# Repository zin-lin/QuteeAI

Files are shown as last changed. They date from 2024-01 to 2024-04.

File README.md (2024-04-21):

# Qutee_v2
Repository for the base code and design of the Qutee V2 robot

# Environment Setup
Setup your Linux environment and Docker.

## Linux
For Linux, you can choose WSL **OR** a VM

### Window Subsystem for Linux ```(WSL)```
Allows a linux distro to run directly on a Windows machine. The default distro will be ```Ubuntu```

- Step 1 - WSL install command
  - Open powershell or windows cmd in administrator mode
  - Enter the command, then restart your machine 

  ```powershell
    wsl --install
  ``` 
*For more info: https://learn.microsoft.com/en-us/windows/wsl/install*
### Virtual Machine ``(VM)``
TBC

## Docker
- Step 1 - Install Docker Desktop
  - Download docker desktop on Windows (https://www.docker.com/products/docker-desktop/)

### ``WSL ONLY``
- Step 2 - Modify Docker Settings
  - Ensure "Use the WSL 2 based engine" is checked.
  - Go to **Settings > Resources > WSL > Enable Integration**

*For more info: https://learn.microsoft.com/en-us/windows/wsl/tutorials/wsl-containers*

---

# Installing `ROS2`

- Step 1 - Set Locale
    ```shell
    locale  # check for UTF-8

    sudo apt update && sudo apt install locales
    sudo locale-gen en_US en_US.UTF-8
    sudo update-locale LC_ALL=en_US.UTF-8 LANG=en_US.UTF-8
    export LANG=en_US.UTF-8

    locale  # verify settings
    ```
- Step 2 - Enable required respositories

    - Enable Ubuntu Universe repository
    ```shell
    sudo apt install software-properties-common
    sudo add-apt-repository universe
    ```

    - Add the ROS 2 GPG key with apt
    ```shell
    sudo apt update && sudo apt install curl -y
    sudo curl -sSL https://raw.githubusercontent.com/ros/rosdistro/master/ros.key -o /usr/share/keyrings/ros-archive-keyring.gpg
    ```

    - Add the repository to your sources list
    ```shell
    echo "deb [arch=$(dpkg --print-architecture) signed-by=/usr/share/keyrings/ros-archive-keyring.gpg] http://packages.ros.org/ros2/ubuntu $(. /etc/os-release && echo $UBUNTU_CODENAME) main" | sudo tee /etc/apt/sources.list.d/ros2.list > /dev/null
    ```

- Step 3 - Install ROS2

    - Update your apt repository caches after setting up the repositories.
    ```shell
    sudo apt update
    ```
    - Make sure system is up to date
    ```shell
    sudo apt upgrade
    ```
    - Install ROS2
    ```shell
    sudo apt install ros-humble-desktop
    ```

- Step 4 - Setup Environment
    ```shell
    source /opt/ros/humble/setup.bash
    ```

- Step 5 - Test
    ```shell
    ros2 wtf
    ```
  -  Should say "All 5 Checks Passed"

*For more info: https://docs.ros.org/en/iron/Installation/Ubuntu-Install-Debians.html*
## Getting Access to Repository on `Linux`
- Step 1
  - In your Linux/Ubuntu VM/Ubuntu App/WSL Powershell, generate SSH key, please keep it out of the repo dir
  ```shell
  ssh-keygen
  ```

- Step 2
  - name the generated key anything you want and skip the `re-paraphrasing` bit
  - this will generate the `$name.pub` file and the `$name`, where the later is the private and the former the public key.
- Step 3
  - Request `zin-lin` on Discord and send your `$name.pub` file's content.
- Step 4
  - activating your key on Local Linux on your system.
  - ```shell
    eval "$(ssh-agent -s)"
    ssh-add path/to/your/private/file/$name
    ```
- Step 5
  - See if your key connection works
  - ```shell
    ssh git@githum.com
    ```
  - The following will be printed if it does
  - ```shell
    PTY allocation request failed on channel 0
    Hi zin-lin/QuteeAI! You've successfully authenticated, but GitHub does not provide shell access.
    Connection to github.com closed.
    ```
- Step 6 
  - Allocate where you want the project and pull
  - ```shell
    mkdir qtai
    cd qtai
    git init
    git remote add origin git@github.com:zin-lin/QuteeAI.git
    git pull origin master
    ```

# Software Compilation and Process
The Software for the Qutee Robot will mainly depend on what hardware component is used during the assembly process.
Use the `Adaptive` folder if you are following what `adaptive-intelligent-robotics` are doing. 
Otherwise, for simple operations and starting with Robotics you may use any other folder inside `software` folder.
The following are components are for all solutions. 

## Electronics Hardware Components

- `12x` XL330 m288t or XL330 m077 Motors [Dynamixel.](https://robotis.co.uk/robotis-dynamixel-xl330-m288-t.html)
- `1x`  Adafruit ESP32s3 Reverse Feather TFT [Adafruit.](https://learn.adafruit.com/esp32-s3-reverse-tft-feather/overview)
  - Do Not buy the [ESP32s3 TFT](https://learn.adafruit.com/adafruit-esp32-s3-tft-feather/overview) because we are not sure if that solution will work or not as the `Dynamixel2Arduino` Library is not transmitting `TX channel` on said board.
- `1x` Dynamixel Shield [Dynamixel.](https://learn.adafruit.com/adafruit-esp32-s3-tft-feather/overview)
- `1x` Dynamixel U2D2 PHB [Dynamixel.](https://emanual.robotis.com/docs/en/parts/interface/u2d2_power_hub/)
- `1x` Dynamixel U2D2 Device [Dynamixel.](https://emanual.robotis.com/docs/en/parts/interface/u2d2/)
- `1x` Arduino Uno Rev 3 Board [Arduino.](https://docs.arduino.cc/hardware/uno-rev3/)
- `1x` Arduino ESP32 Nano [Arduino.](https://docs.arduino.cc/hardware/nano-esp32/)

### Please follow the commands under the software folder to deal with Firmware build and flash.

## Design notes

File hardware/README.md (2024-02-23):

## CAD Design ##
The design of the robot can be found [online with Fusion 360](https://a360.co/49cv0nH).

[Also Here](https://myhub.autodesk360.com/ue2c9bb1e/g/shares/SH512d4QTec90decfa6e1e6c72c091da29c5).

## Print List ##
The STLs of the different elements are available in the STL folder. Here is the print list:
|  Qty | Name of the file  | 
|---|---|
| 1x |body_base|
| 1x |body_bottom|
| 1x |case|
| 1x |case_botom|
| 4x |doubleU|
| 4x |foot|
| 12x |horn|
| 12x |horn_spacer|
| 8x |side|
| 1x |spacer|
| 4x |tibia|

## Bill of Material ##
|  Min. Qty. | Reference  | Example of provider | 
|---|---|---|
|12x| Motor: Robotis - Dynamixel XL330-M288-T| https://robosavvy.co.uk/robotis-dynamixel-xl330-m288-t.html|
|1x| Micro-controller: Adafruit ESP32-S3 Reverse TFT Feather - 4MB Flash, 2MB PSRAM, STEMMA QT (for non-TFT: Adafruit ESP32-S3 Feather with 4MB Flash 2MB PSRAM - STEMMA QT / Qwiic| [https://shop.pimoroni.com/products/adafruit-esp32-s3-feather-with-4mb-flash-2mb-psram-stemma-qt-qwiic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](https://thepihut.com/products/adafruit-esp32-s3-reverse-tft-feather-4mb-flash-2mb-psram-stemma-qt)|
|1x| IMU: Adafruit 9-DOF Absolute Orientation IMU Fusion Breakout - BNO055 (STEMMA QT / Qwiic)| [https://robosavvy.co.uk/sparkfun-9dof-imu-breakout-ism330dhcx-mmc5983ma-qwiic.html](https://thepihut.com/products/adafruit-9-dof-absolute-orientation-imu-fusion-breakout-bno055-stemma-qt-qwiic)|
|1x| IMU cable: Flexible Qwiic Cable - 100mm| https://robosavvy.co.uk/flexible-qwiic-cable-100mm.html|
|1x| Battery: 2/3 AF 1600mAh 4.8V Square Premium Sport NiMH Battery| https://www.overlander.co.uk/nimh-batteries/4-8v-4s/2-3-af-1600mah-4-8v-square-premium-sport-nimh-battery.html (You will need a charger for this too). |
|1x| Power Board: ROBOTIS - U2D2 PHB SET| https://robosavvy.co.uk/robotis-u2d2-phb-set.html|
|1x| Battery connector: Molex, Mini-Fit Jr Receptacle Connector Housing, 4.2mm Pitch, 2 Way, 2 Row| https://uk.rs-online.com/web/p/wire-housings-plugs/4841748|
|2x| Battery connector contacts: Molex MINI-FIT Series, 5556 Series Number, Crimp Contact, Female, 24AWG to 18AWG, Tin Plating| https://uk.rs-online.com/web/p/crimp-contacts/1729134|
|100x| screw: Pozidriv Countersunk M2x10mm|https://uk.rs-online.com/web/p/machine-screws/1795670 |
|100x| screw: Pozidriv Pan M2x5mm|https://uk.rs-online.com/web/p/machine-screws/9141466| 

# for custom cables: #
The cables are made in-house at custom length. This is not mandatory, it just allows better cable management. Otherwise, the cables that come with the motors should be enough to build the robot (not tested). To make custom cables, you will need: 
|  Min. Qty. | Reference  | Example of provider | 
|---|---|---|
|1x| |https://uk.rs-online.com/web/p/hook-up-wire/8417263|
|1x| |https://uk.rs-online.com/web/p/insertion-extraction-tools/3253500|
|1x| |https://uk.rs-online.com/web/p/crimp-tools/4482355|
|75x| |https://uk.rs-online.com/web/p/crimp-contacts/3116439|
|24x| |https://uk.rs-online.com/web/p/wire-housings-plugs/1724910|

# optional #
If you don't want to print the horns and horn_spacers, you can buy the following which provides 4 pairs along with the frame that is not used. 
|  Qty | Name  | Example of provider | 
|3x| spacers and horns: FPX330-H101 4PCS SET| https://robosavvy.co.uk/fpx330-h101-4pcs-set.html (I used the spacers from this kit, but I will check in the near future if that can be 3d printed)|

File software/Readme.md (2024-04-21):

# Firmware
Please read the main Readme before reading this. 
There solutions are provided 
1) Using `esp32s3` (8MB for RAM) - Developed by [adaptive-intelligent-robotics](https://github.com/adaptive-intelligent-robotics/Qutee_v2)
   - wifi ✅, self-processing ✅, usb-debugging ❌
2) Using `Arduino Uno` and potentially wifi `Nano-esp32` (very powerful at 16MB of RAM for a microcontroller). Self-development
   - wifi ✅, self-processing ✅, usb-debugging -`testing`
3) Using `U2D2 device` (No RAM). Self-development
   - wifi ❌, self-processing ❌, usb-debugging ✅
###
- #### For the first solution please visit the repository made by the original developers.

### Hardware preparation 

- Before we do anything with the code the Dynamixel motors are needed to be set up so that all three solutions are usable.
- The servos when they come in, all have the `ID = 1`, which needed to be changed to `11`, `12`, `13`, `21`, `22`, `23`, `31`, `32`, `33`, `41`, `42`, `43`
- This can be done using the `U2S2` device and `Dynamixel Wizard` Application [Dynamixel](https://emanual.robotis.com/docs/en/software/dynamixel/dynamixel_wizard2/)
  - Please download this application on your PC.
  - Then connect the U2D2 device with the PC using USB-A and start the `Dynamixel Wizard`.
  - Just to be sure you must select to update the firmware on the servo
    - Select the right model and upload firmware
    - Then hit scan 
    - and now you will see your servo
    - set the ID to the ones given above
    - Note: do this one by one: do not daisy-chain them 
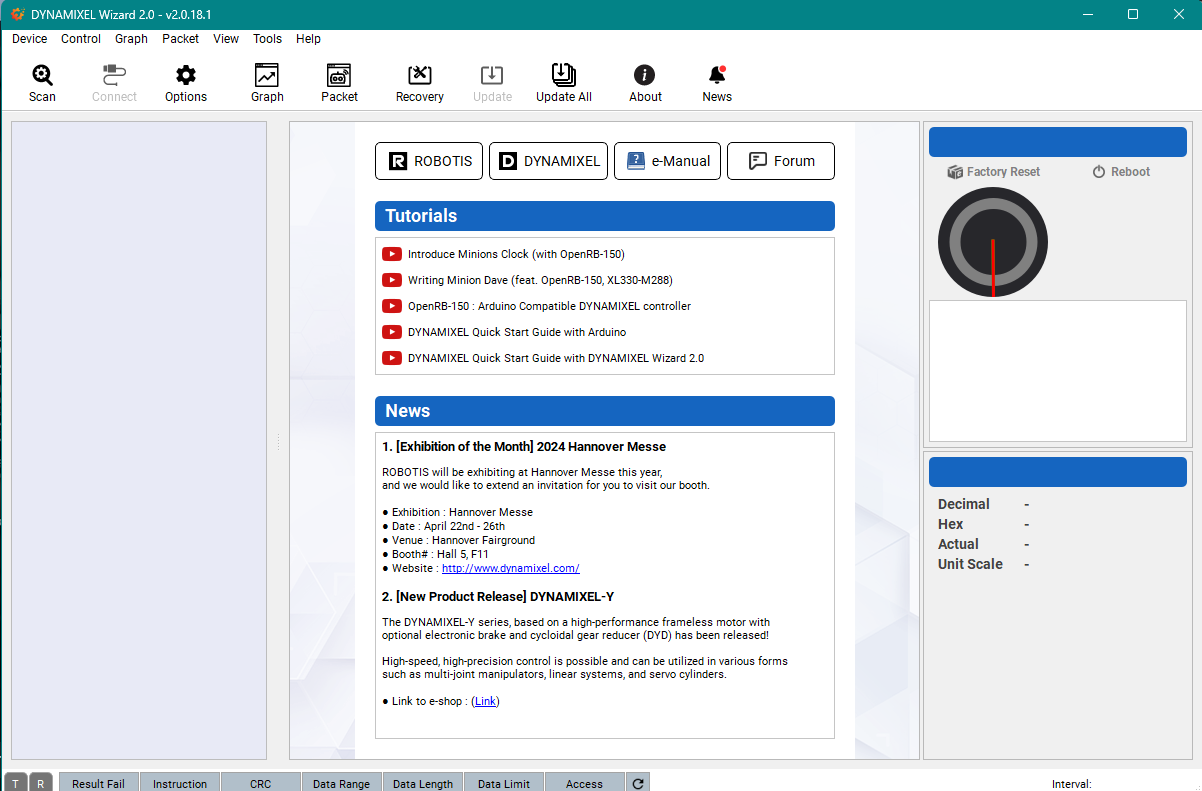
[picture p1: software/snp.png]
Wizard
    - 
- We must now continue to create Y cables out of the two given 3 pins wires (`GND`, `VAT`, `DATA`). 
This is because either if we use U2D2 PHB, or the Dynamixel shield solutions or the U2D2 solution, we still will have only two available 3pin Dynamixel slots. We need four legs.
- Thus 2, 3pin wires must be crimped. 

### Solution 1
- For the first solution, one must connect the GND pin on the ESP32s3 to the GND pin on one of the sockets of the 3 pin ports on the PHB.
Then the VBat to the VAT line and use crimps to connect two wires which are soldered to A0 and A1, which then connects to the data line on the PHB.
    - ESPCon
- Then use the remaining two ports to connect to the Y cables created earlier for four legs. Each port will control two legs
- Now we can daisy-chain the legs.
- Remember to keep the order on 
  - `leg 1` - `11` , `12`, `13`
  - `leg 2` - `21` , `22`, `23`
  - `leg 3` - `31` , `32`, `33`
  - `leg 4` - `41` , `42`, `43`
 - Software solution for this should be followed as instructed by the Original Developers on the given url.

### Solution 2
- For the second solution, using the Arduino boards one must download the Arduino IDE
- then through package manager, one must download the Arduino Uno Support Libraries
- Still in testing later use for processing and cloud connection download `Nano ESP32 Arduino` library as well.
- The next thing that one needs are the `DynamixelSheild` and `Adafruit_BNO055` library. This has to be downloaded via Library Manager as well.
- The current status of this solution is that it can walk, WiFi and imu will be added later using the `Nano ESP32 Arduino`
- Here the hardware components are easier to manage. 
  - Connect the Arduino Board and the Sheild by stacking them, they should fit perfectly.
  - Connect the four terminal servos as solution 1 to the shield just like to the PHB. 
  - Move the shield switch to UART and upload the `solution_flash.ino` file onto the board.
  - Hit RsT button 
  - The robot should start moving
  - disconnect batteries to stop.
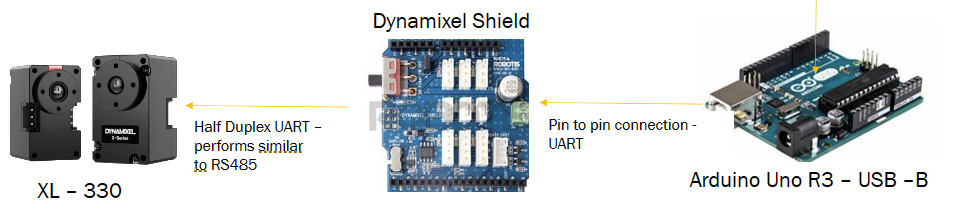
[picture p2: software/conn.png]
Connection
  - 

### Solution 3
- This is using the U2D2 and the PHB set for it 
- For this you would need to set up the `USB - A` Connection between the PC and the U2D2 device.
- This device can be mounted on top of the PHB board and connect to the pin board using Dynamixel 3 pin cables.
- Now the set up of the motors should be the same as Solution 1, where the remaining 3 pin sockets should be connected to the Y cable, each managing two legs worth of servos.
- Before running the code run
  - ```shell
    pip3 install dynamixel_sdk
    ```
- Run the code, remember to replace the `Dev/ttyACM0` with your correct port.
- If running on WSL make sure to download `USBIPD-WIN` and use binding to use port.
  - ```shell
    usbipd list
    usbipd bind  --busid <your-bus-id>
    usbipd attach --wsl --busid <your-bus-id>
    ```
- You can use docker to build this solution by using the Dockerfile as well. But remember to allow Docker to share port as well.

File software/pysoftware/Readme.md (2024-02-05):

# Damian's way for deploying https and http -VM name/VM IP with Caddy and Flask/wsgi-waitress

- Step 0: make sure `your_repo` in `gen-waitress.sh` is `your repo address/folder` and `Description=Your App Name` is actually `Description= whatever_you_want_to_name_it` and also in your Caddyfile change `xx` to `your napier machine no. example 23`
- Step 1: run 
```powershell
chmod +x run.sh
```
- Step 2: run the file
if installation needed/ run for the first time
```powershell
./run.sh install
```
else run after changes
```
./run.sh
```

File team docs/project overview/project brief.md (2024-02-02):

## Build a quadruped robot for Artificial Intelligence research
Edinburgh Napier University
C++ , GIT , Linux , Machine learning , Microprocessors , Python , Raspberry Pi , Sensors

#### Overview
With the use of 3D printers and accessible hardware like micro computers and servo motors, we can build robots in-house that are ready to be used in academic research. In this project, the group will build and test a Qutee robot. The Qutee is an open-source quadruped robot. All the parts to build the robot are easily found on the market and 3D printed with the facilities at ENU.

The group will 3D print the legs and body of the robot, assemble them, including the motors, controller (CPU and motor hub) and battery. Then, the group will program the robot to tests its capacities. The second part of the project includes the use of artificial intelligence to make the robot autonomous. At this point, several techniques can be applied, like machine learning, evolutionary computation or intrinsic motivations.

An example of the robot used for research can be found here: https://arxiv.org/abs/2304.12080 https://www.youtube.com/watch?v=BgGNvIsRh7Q

#### Deliverables
The main deliverable is the robot itself. The robot will be 3D printed by the students using the printers and material provided by the university. The university will provide all the hardware also to fully assemble the robot: motors, controller, cabling, etc.

Other deliverable include the software to control the robot. This code can be stored in our git repository. This software should include the actions to send to the motors (joint angle position) and the reading of the sensors included in the robot (IMU, joint positions, etc). An interface to the most used robotic software like Python and ROS can be built for this project.

Last deliverable is the autonomous control of the robot using some of the AI techniques mentioned before.

A report with a list of improvements for future iterations of the robot.

#### Resources
All the hardware necessary to print the robot parts (3D printers, plastic material, etc).

The hardware to assembly the robot (motors, sensors, controller, cables, battery, charger, etc).

CAD description for the 3D printed parts.

Access to lab B62 to work on the robot and print the parts.

The software can be written in any language but Python or C++ are the most used for robotics.

Knowledge of ROS is a plus but not required. Knowledge of AI and machine learning is also a plus but is not required.

#### Contact details
The client will contact you after you form a team and register a bid for the project.

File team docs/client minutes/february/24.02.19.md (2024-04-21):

## Client Meeting Minutes  

Date:19/02/2024  
Location: B62

Client: Simón Smith, C82e
Sponsor: Alex Gkanatsios, B69b

Attendees:

|Name|Role|In Person|Online|
|:--|:--|:--:|:--:|
|Malcolm Byrnes| PM | [x] | [ ] |
|Guy Cameron | Test Lead | [x] | [ ] |
|Zin Htun | Software Lead | [ ] | [x] |
|Nicole Jordaan | Scrum Master | [ ] | [x] |
|Aman Mishra | Hardware Lead | [x] | [ ] |
|Andrew Taison | PO | [x] | [ ] |

---  

#### Progress:  
(Since last meeting)  

* Reply from github repo owners  
* 3d parts stl files have been modified  
* Purchased parts have been delivered (missing 7 motors as mentioned last week)  
* Can now visualise URDF files  

---  

#### Agenda:  
(What was discussed)  

* Reply recieved from github repo owners, they are flushing software to micro-controller, still communicating with them. Don't think ESP can handl ROS2, suspect one module is not compatible  
* STL of new version of leg (one part) has been completed, all printing is expected to be complete by late tomorrow
* Expecting to start looking at soldering boards and testing motors tomorrow  
* Documentation on dynamixel for voltages to send to motors and how to connect etc. **Important** to not damage motors as will not be able to get any more  
* Client appreciates documentation being created  
* Can visualise URDF, but struggling to intergrate STL or dae files as mesh to create URDF  

---  

#### Decisions:  
(Project decisions made)  

* Read (joint positions/IMU) along with ability to set joint positions is sufficient for project - worrying about communication via ROS etc can be a later issue    
* Need to use these motors - as only have 5, can only assemble what we have. Maybe assemble rest in a way that can be disassembled easily when other motors arrive. Should have ability to move a little, even crawling  
* Ok to create URDF file with basic shapes instead of using STL, this can maybe be added later to make it look better if can find a way to intergrate, but a lower priority. Can potentially get center of mass values for URDF from fusion (need to look into), however, will be ok to use center of part as center of mass, and set mass as 0.1kg or something (very light - NOT zero)  

---  

#### Action Items:  
(Items to be completed, reponsible person and completion date if applicable)  

* Send video to Simon if build robot and have it moving (even if just 1 leg) - **@everyone**  
* Start URDF creation for actual robot with basic shapes - **@Andy**  
* Look into obtaining part details (mass / center of mass / inertia details etc) from fusion 360 - **@Guy**  
* Look into if its possible to integrate STL files with URDF (or if theres a specific file type that URDF allows for mesh files) - **@Guy**  
* Test motors - **@Damian**  
* Start documentation - **@Nicole**  
* Start soldering IMU/ada/power board pins - **@Aman / @Andy**  
* Management duties, docs, collect parts - **@Malcolm**  

---  

#### Next Meeting:
(When and where)  

* Monday 26th February - B62 and online

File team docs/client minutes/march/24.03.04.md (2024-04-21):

## Client Meeting Minutes  

Date: 04/03/2024  
Location: B62

Client: Simón Smith, C82e
Sponsor: Alex Gkanatsios, B69b

Attendees:

|Name|Role| In Person | Online |
|:--|:--|:---:|:-----:|
|Malcolm Byrnes| PM | [x] |  [ ]  |
|Guy Cameron | Test Lead | [x] |  [ ]  |
|Zin Htun | Software Lead | [x] |  [ ]  |
|Nicole Jordaan | Scrum Master | [x] |  [ ]  |
|Aman Mishra | Hardware Lead | [ ] |  [x]  |
|Andrew Taison | PO | [x] |  [ ]  |

---  

#### Progress:  
(Since last meeting)  

* Most parts have been printed  
* Original code is compiling  
* Soldering the board has started

---  

#### Agenda:  
(What was discussed)  
* Discussed Reprinting of TFT spacer - Needs to be done ASAP and sent to Alex 
* Showed URDF file to client
* Discussed URDF file is able to be opened in Issac Gym but collisions haven't been setup
* Discussed minor changes to URDF file
* Discussed battery cable modification
* Discussed how motors are to be connected to microcontroller 
---  

#### Decisions:  
(Project decisions made)  

* Building the robot can be started

---  

#### Action Items:  
(Items to be completed, reponsible person and completion date if applicable)  

* Collisions  to be added to URDF file
* The battery cable will need to be modified to connect to power board
* Ask original developers how to connect the motors to  microcontroller 

---  

#### Next Meeting:
(When and where)  

* Monday 11th March - B62 and online

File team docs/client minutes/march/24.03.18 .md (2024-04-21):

## Client Meeting Minutes  

Date: 18/03/2024  
Location: B62

Client: Simón Smith, C82e
Sponsor: Alex Gkanatsios, B69b

Attendees:

|Name|Role| In Person | Online |
|:--|:--|:---:|:-----:|
|Malcolm Byrnes| PM | [x] |  [ ]  |
|Guy Cameron | Test Lead | [x] |  [ ]  |
|Zin Htun | Software Lead | [x] |  [ ]  |
|Nicole Jordaan | Scrum Master | [x] |  [ ]  |
|Aman Mishra | Hardware Lead | [x] |  [ ]  |
|Andrew Taison | PO | [x] |  [ ]  |

---  

#### Progress:  
(Since last meeting)  

* Motors are working and we have basic control
* Construction in progress
* All parts now printed
* Different battery being used as previous was incompatible
* Old battery not enough voltage, needs to be larger

---  

#### Agenda:  
(What was discussed)  
* Discussed problems with power from battery
* Discussed and solved clearance issues with double u and legs
---  

#### Decisions:  
(Project decisions made)  

* Continue building robot

---  

#### Action Items:  
(Items to be completed, reponsible person and completion date if applicable)  

* Forget battery and use wired power
* Continue working with u2d2
* Forget wifi
* Try to connect imu to read the state of the motors
* Use different screws for connecting double u and legs

---  

#### Next Meeting:
(When and where)  

* Unknown? Probably after Easter Break

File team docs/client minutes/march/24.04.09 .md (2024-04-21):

## Client Meeting Minutes  

Date: 09/04/2024  
Location: E13

Client: Simón Smith, C82e\
Sponsor: Imed Romdhani, C64

Attendees:

|Name|Role| In Person | Online |
|:--|:--|:---:|:-----:|
|Malcolm Byrnes| PM | [x] |  [ ]  |
|Guy Cameron | Test Lead | [ ] |  [ ]  |
|Zin Htun | Software Lead | [x] |  [ ]  |
|Nicole Jordaan | Scrum Master | [x] |  [ ]  |
|Aman Mishra | Hardware Lead | [x] |  [ ]  |
|Andrew Taison | PO | [x] |  [ ]  |

---  

#### Progress:  
(Since last meeting)  

* Robot mostly build
* New crimps and molex arrived
* Attempted implementation with wifi
* URDF updated

---  

#### Agenda:  
(What was discussed)  
* Discussed potential problem with either software or hardware
* Discussed connecting wires, crimps too small, y cable could be potential solution
* start of project closure
---  

#### Decisions:  
(Project decisions made)  

* Continue building robot
* Use arduino uno for demo, stick it on robot temporarily
* Write documentation on hardware and software
* work on solutions for cables
* scrapping esp idea

---  

#### Action Items:  
(Items to be completed, reponsible person and completion date if applicable)  

* mounting arduino uno onto robot
* sort cabling out

---  

#### Next Meeting:
(When and where)  

* 15/04/2024 B62

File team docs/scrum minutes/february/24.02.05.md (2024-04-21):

## Scrum Meeting Minutes  

Date: 05/02/2024 
Location: --

Client: Simón Smith, C82e
Sponsor: Alex Gkanatsios, B69b

Attendees:

|Name|Role|In Person|Online|
|:--|:--|:--:|:--:|
|Malcolm Byrnes| PM | [ x ] | [ ] |
|Guy Cameron | Test Lead | [ x ] | [ ] |
|Zin Htun | Software Lead | [ x ] | [ ] |
|Nicole Jordaan | Scrum Master | [ x ] | [ ] |
|Aman Mishra | Hardware Lead | [ x ] | [ ] |
|Andrew Taison | PO | [ x ] | [ ] |

---  

#### Blockers:  
(What cannot progress, why, any actions required to continue?)  

*  Still waiting for parts to print.
*  Still waiting for electronic components to arrive.
*  Software is confusing to read and cannot build it.

---  

#### Progress:  
(Since last meeting)  

*  Most sections of the IR report have been completed.
*  Most people (4/6) have Linux with Docker setup.

---  

#### Agenda:  
(What was discussed)

*  Who still needs to set up Linux and Docker.
*  What still needs to be done with the IR report.
*  How to modify the top case to accommodate the new design of the microcontroller.
*  What is URDF file and how to create one.

---  

#### Decisions:  
(Project decisions made)  

* Made the descion to try to use fusion 360 to modify the case

---  

#### Action Items:  
(Items to be completed, reponsible person and completion date if applicable)  

*  Complete Executive Summary Section of the IR report - assigned to Malcolm
*  Stakeholders Map needs to be added to IR Report - assigned to Aman
*  Expected Costs and Duration section needs to be reviewed - assigned to Nicole
*  Research URDF file - assigned to Andy
*  Research Fusion 360 - assigned to Guy
*  Research ROS2 - assigned to Zin 

---  

#### Next Meeting:
(When and where)  

*   12/02/2024 on Campus

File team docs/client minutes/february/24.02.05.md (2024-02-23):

## Client Meeting Minutes  

Date:05/02/2024  
Location: B62

Client: Simón Smith, C82e
Sponsor: Alex Gkanatsios, B69b

Attendees:

|Name|Role|In Person|Online|
|:--|:--|:--:|:--:|
|Malcolm Byrnes| PM | [x] | [ ] |
|Guy Cameron | Test Lead | [x] | [ ] |
|Zin Htun | Software Lead | [x] | [ ] |
|Nicole Jordaan | Scrum Master | [x] | [ ] |
|Aman Mishra | Hardware Lead | [x] | [ ] |
|Andrew Taison | PO | [x] | [ ] |

---  

#### Progress:  
(Since last meeting)  

* Continued initiation report  
* 

---  

#### Agenda:  
(What was discussed)  

* Parts still not here - follow up email has been sent (by Simon) **"Pending stock"**
* Discussed stakeholder map  
* Discussed Git Software for project - Libraries discontinued  

---  

#### Decisions:  
(Project decisions made)  

* Robot would not be expected to move in a perfect straight line  

---  

#### Action Items:  
(Items to be completed, reponsible person and completion date if applicable)  

* Simon to look into alternatives for motors if unable to obtain (do to stock issues) **@Simon**  
* Look into Fuision 360 for adjusting design for case to accomodate dev board  
* Research URDF files  

---  

#### Next Meeting:
(When and where)  

* Monday 12th February - B62 and online

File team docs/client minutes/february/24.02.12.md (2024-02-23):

## Client Meeting Minutes  

Date:12/02/2024  
Location: B62

Client: Simón Smith, C82e
Sponsor: Alex Gkanatsios, B69b

Attendees:

|Name|Role|In Person|Online|
|:--|:--|:--:|:--:|
|Malcolm Byrnes| PM | [x] | [ ] |
|Guy Cameron | Test Lead | [x] | [ ] |
|Zin Htun | Software Lead | [x] | [ ] |
|Nicole Jordaan | Scrum Master | [x] | [ ] |
|Aman Mishra | Hardware Lead | [x] | [ ] |
|Andrew Taison | PO | [x] | [ ] |

---  

#### Progress:  
(Since last meeting)  

* Finished and submitted PIR  
* Printing continues   
* Looked into fusion  
* Looked into URDF files  

---  

#### Agenda:  
(What was discussed)  

* Parts still not here - Simon has contacted the company, 7 missing motors which may not be delivered. But is happy that what should get delivered should be enough to build part of the robot and test. The parts the company have, should be here by next week  
* Research purpose of robot is 'Damage recovery'  
* Software update - no reply from git repo owner, can complete without. Looking into wireless version. Can compile code, but issue finding include files   
* Client has found contacts for rubber parts, but not sure what they can produce just yet - Simon will look into this further  
* Will be a delay on getting bolts for feet / legs  

---  

#### Decisions:  
(Project decisions made)  

* 

---  

#### Action Items:  
(Items to be completed, reponsible person and completion date if applicable)  

* Look into Robot Dart and Gazebo for URDF visuals as GYM does not show visual when working on URDF **@Andy**  
* Also look into how to use URDF with GYM **@Andy**  
* List printed parts and those to be adjusted/printed, send to Alex and Simon **@Malcom**  
* Can we connect to TFT? Test if we can communcate with boards **@Damian & @Nicole**   
* Issue with include files may be solvled by adding path to make file. Check paths are availiable inside of docker container **@ & @Nicole**  
* Look into modifying feet/leg files so can be printed as a single part **@Guy & @Aman**  
* Measure boards and modify printed part files as required **@Guy**  

---  

#### Next Meeting:
(When and where)  

* Monday 19th February - B62 and online

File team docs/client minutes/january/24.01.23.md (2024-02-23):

## Client Meeting Minutes  

Date: 23/01/2024  
Location: B62

Client: Simón Smith, C82e
Sponsor: Alex Gkanatsios, B69b

Attendees:

|Name|In Person|Online|
|:--|:--:|:--:|
|Malcolm Byrnes| [x] | [ ] |
|Guy Cameron | [x] | [ ] |
|Zin Htun | [x] | [ ] |
|Nicole Jordaan | [x] | [ ] |
|Aman Mishra | [ ] | [ ] |
|Andrew Taison | [x] | [ ] |

---  

#### Agenda:  
(What was discussed)  

* Brief from Client - Overview of project  
* Access to lab B62 should be given in next week or so  
* Printing can start soon, Alex will email Malcolm when parts ready to collect  
* Can only print between 9-5 & requires someone in lab  

---  

#### Decisions:  
(Project decisions made)  

* Want access to sensor info  
* Robot should be more robust than standard as using for research  
* Leg motors to be wired in series  
* Configure motors using dynamixel wizard 2.0 software  
* To build URDF file so can be simulated in Gym  

---  

#### Action Items:  
(Items to be completed, reponsible person and completion date if applicable)  

* Send matric numbers and timetables to Simon  
* Fork repo - https://github.com/adaptive-intelligent-robotics/Qutee_v2  

---  

#### Next Meeting:
(When and where)  

* Tuesday 30th January - B62 and online

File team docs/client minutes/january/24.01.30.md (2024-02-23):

## Client Meeting Minutes  

Date: 30/01/2024  
Location: B62

Client: Simón Smith, C82e
Sponsor: Alex Gkanatsios, B69b

Attendees:

|Name|Role|In Person|Online|
|:--|:--|:--:|:--:|
|Malcolm Byrnes| PM | [ ] | [x] |
|Guy Cameron | Test Lead | [ ] | [x] |
|Zin Htun | Software Lead | [x] | [ ] |
|Nicole Jordaan | Scrum Master | [x] | [ ] |
|Aman Mishra | Hardware Lead | [ ] | [ ] |
|Andrew Taison | PO | [x] | [ ] |

---  

#### Progress:  
(Since last meeting)  

* Access has been given to lab  
* Github has been setup  
* Zube has been setup  
* Started initiation report  

---  

#### Agenda:  
(What was discussed)  

* Confirmed details for initiation report  
* All printed parts should be completed by mid/late next week  
* All ordered parts should be arriving by next week - still waiting on Motors, cable and power board    
* URDF file requires XML format for dimentions from SDL file  

---  

#### Decisions:  
(Project decisions made)  

* MoSCow decided upon - see PIR  
* Sensor data to include joint positions (rotation angle) - should have access via IMU board  
* ROS topic to output sensor data (Could have item)  

---  

#### Action Items:  
(Items to be completed, reponsible person and completion date if applicable)  

* Research how to connect boards - should be able to find documentation online - **@Aman**  
* Need to find solution to assemble feet as parts are not rubber  
* Some parts are completed printing, ready to sand - **@Andrew**  
* PIR report to be completed and then signed off by client  
* Continue setup for ROS and Docker - **@Zin**  
* Should about be in a position to look at modifying case  

---  

#### Next Meeting:
(When and where)  

* Monday 5th February - B62 and online

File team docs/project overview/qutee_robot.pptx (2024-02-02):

## Qutee Robot

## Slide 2

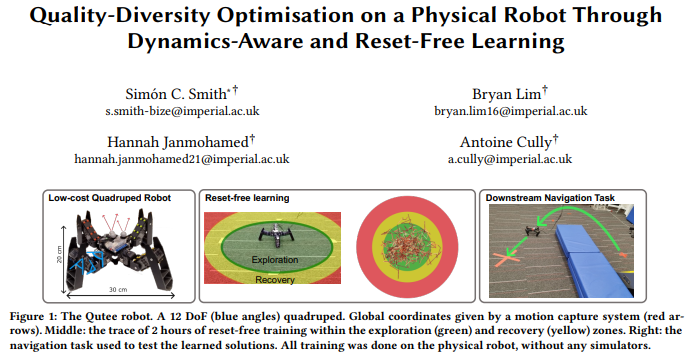
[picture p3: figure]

https://www.youtube.com/watch?v=BgGNvIsRh7Q

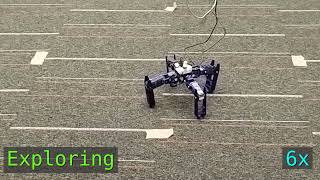
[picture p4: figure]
Quality-Diversity Optimisation on a Physical Robot Through Dynamics-Aware and Reset-Free Training Gecco 2023. Learning algorithms, like Quality-Diversity (QD), can be used to acquire repertoires of diverse robotics skills. This learning is com- monly done via computer simulation due to the large n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

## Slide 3

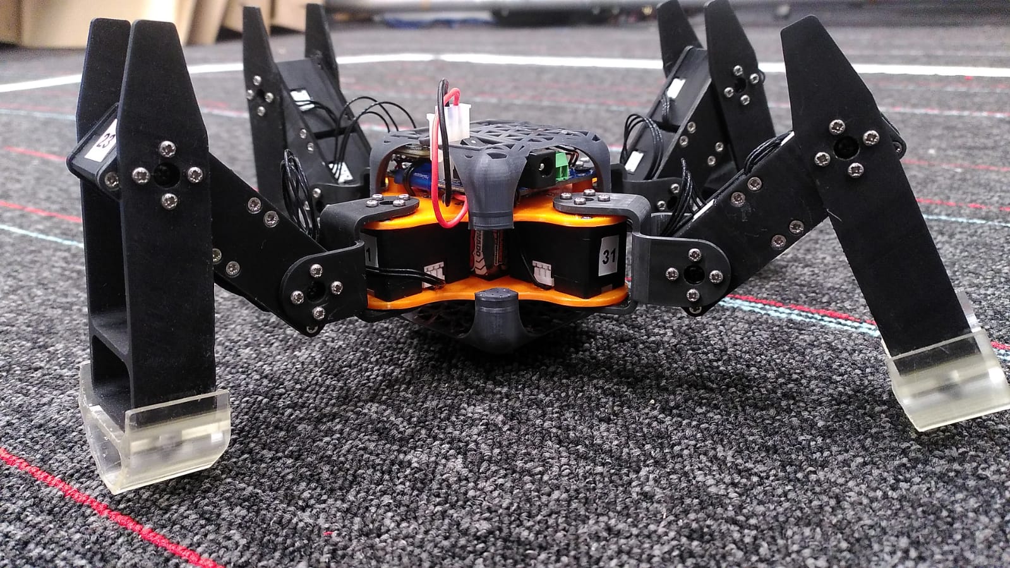
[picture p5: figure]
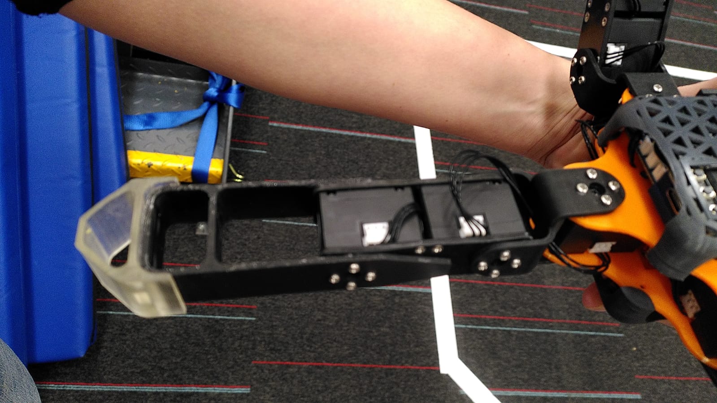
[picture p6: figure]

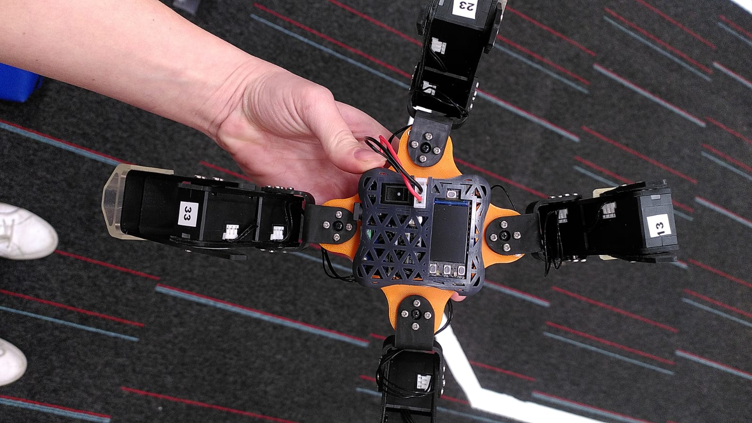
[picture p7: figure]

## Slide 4

- Quadruped
- 12 DoF
- Sensing:
  - Proprioception (joint positions)
  - v2: Exteroception (IMU)
- Acting
  - 12 Dynamixel motors
- Control:
  - Onboard
  - Off-board (wifi) v2
- Battery power
- Hardware and software:
  - https://github.com/adaptive-intelligent-robotics/Qutee_v2
- Python
- ROS2

## Things to do

- 3D print
- Update design for controller Adafruit ESP32-S3 TFT Feather ]
- Wait for hardware to arrive (already purchased)
- Assembly
- Software:
  - Dynamixel Wizard (to control the motors)
  - Python (to put all together)
  - ROS2 to connect over network
  - Use our repo: git.napier.ac.uk (ask for access)
    - Clone original repo, work from there.
  - Build URDF file

## AI

- Robust control
- Navigation
- Optimisation
- SLAM
- Other
  - Remote interface
  - Add arm

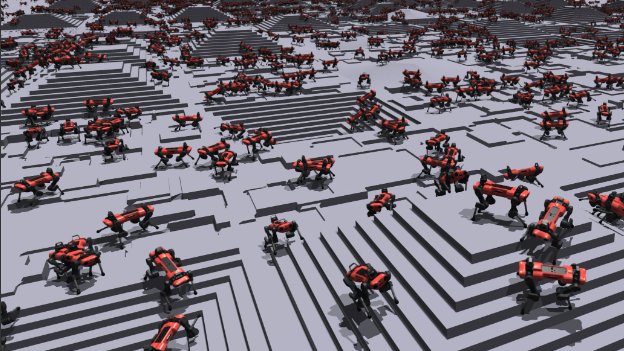
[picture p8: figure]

- Use NVidia Isaac Gym for Machine learning
  - Reinforcement learning
- Use Evolutionary Computation
- Use ROS2 packages, for example SLAM

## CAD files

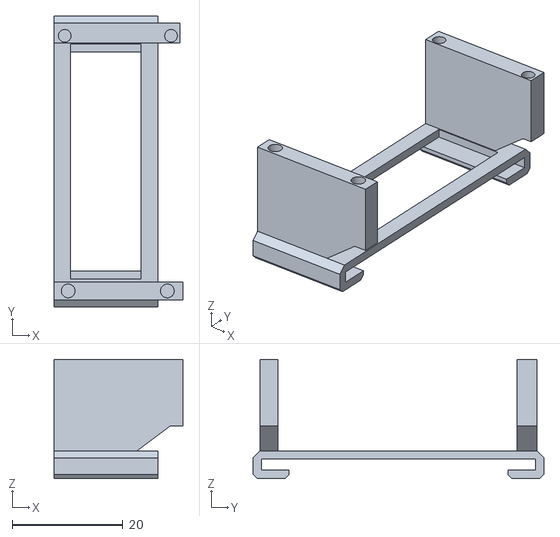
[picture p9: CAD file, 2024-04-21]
hardware/STL/new_spacer.stl
23.3 x 52.5 x 21.5

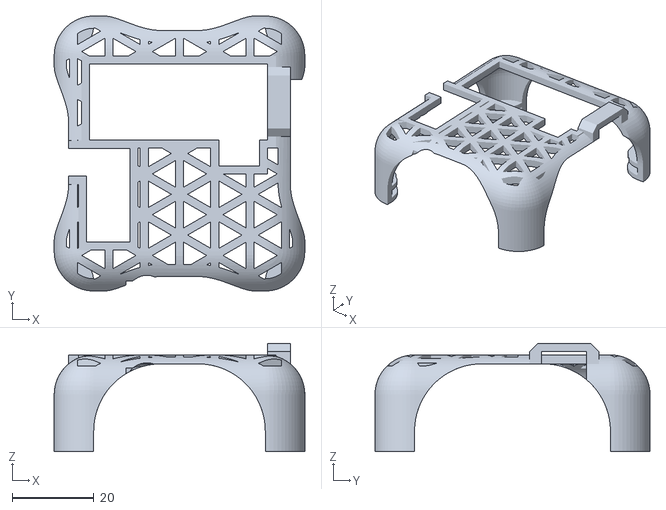
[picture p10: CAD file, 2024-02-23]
hardware/STL/Case_tft.stl
61.5 x 67.4 x 26.5

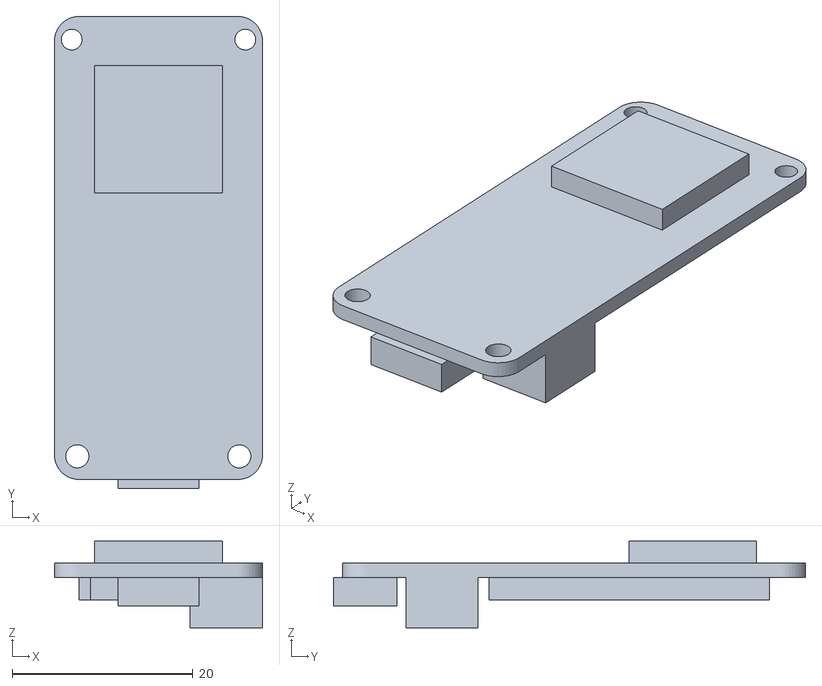
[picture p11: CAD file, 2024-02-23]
hardware/STL/esp32-S3-tft-reverse.stl
23.0 x 52.2 x 9.60

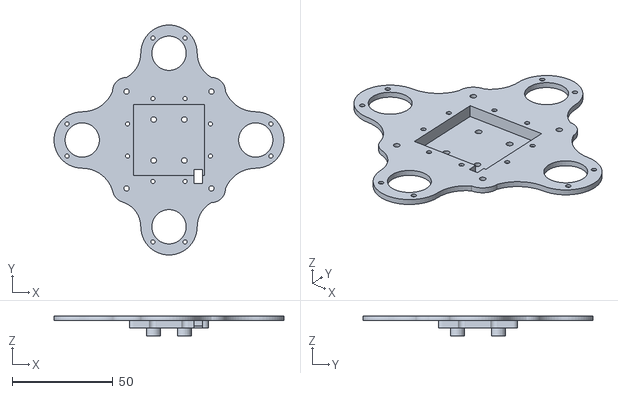
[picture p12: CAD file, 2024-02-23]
hardware/STL/body_bottom.stl
114.0 x 114.0 x 9.80

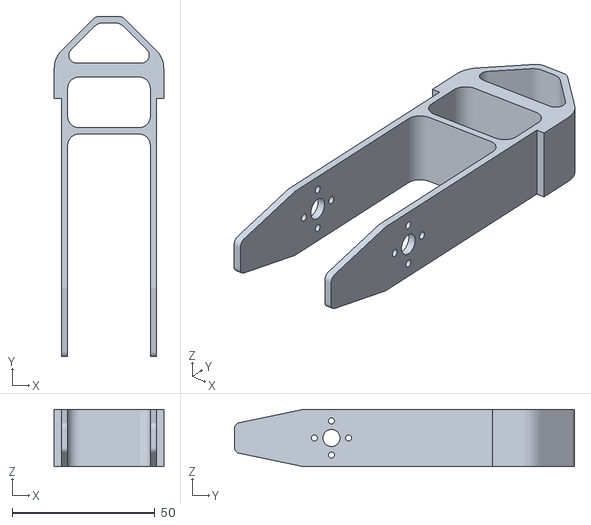
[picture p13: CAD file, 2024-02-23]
hardware/STL/leg.stl
38.4 x 119.2 x 20.0

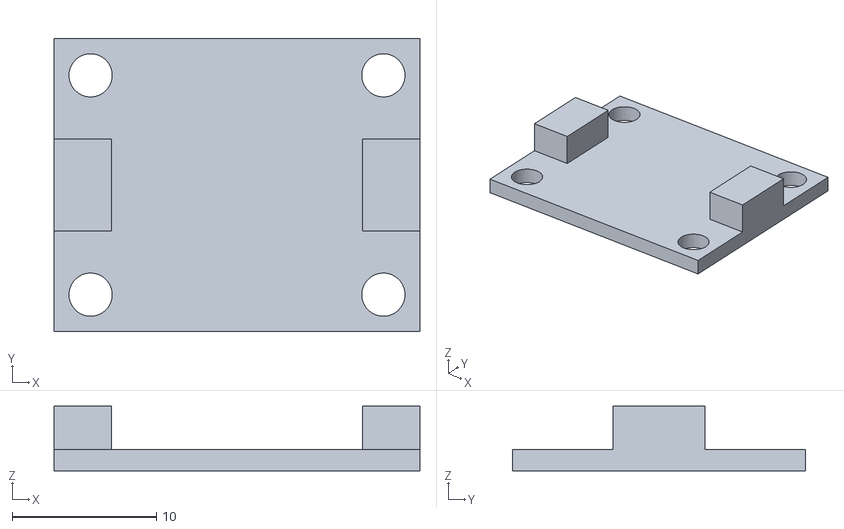
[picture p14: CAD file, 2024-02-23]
hardware/STL/imu.stl
25.4 x 20.3 x 4.50

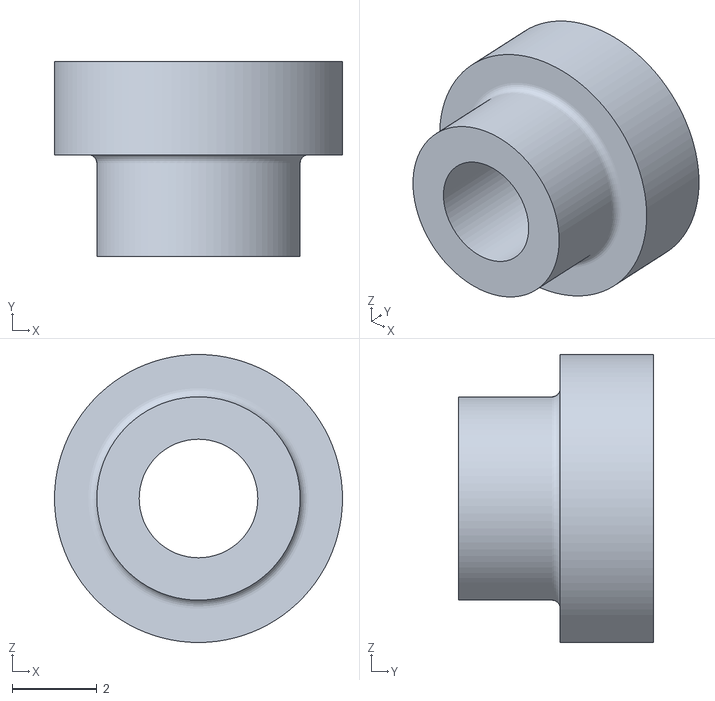
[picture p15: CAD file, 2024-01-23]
hardware/STL/horn_spacer v2.stl
6.80 x 4.60 x 6.80

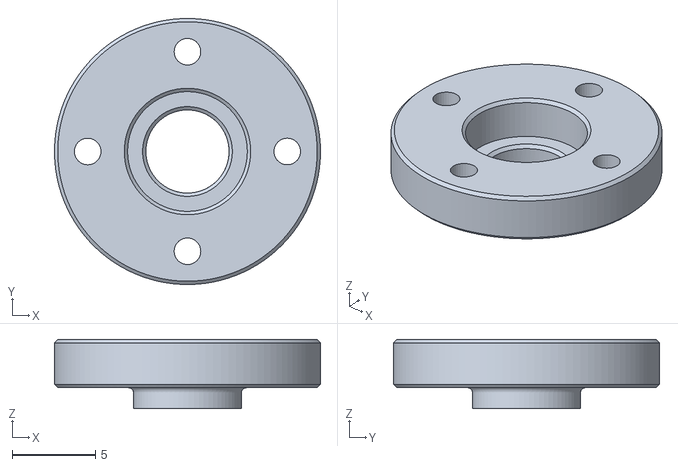
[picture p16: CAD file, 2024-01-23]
hardware/STL/horn v1.stl
16.0 x 16.0 x 4.15

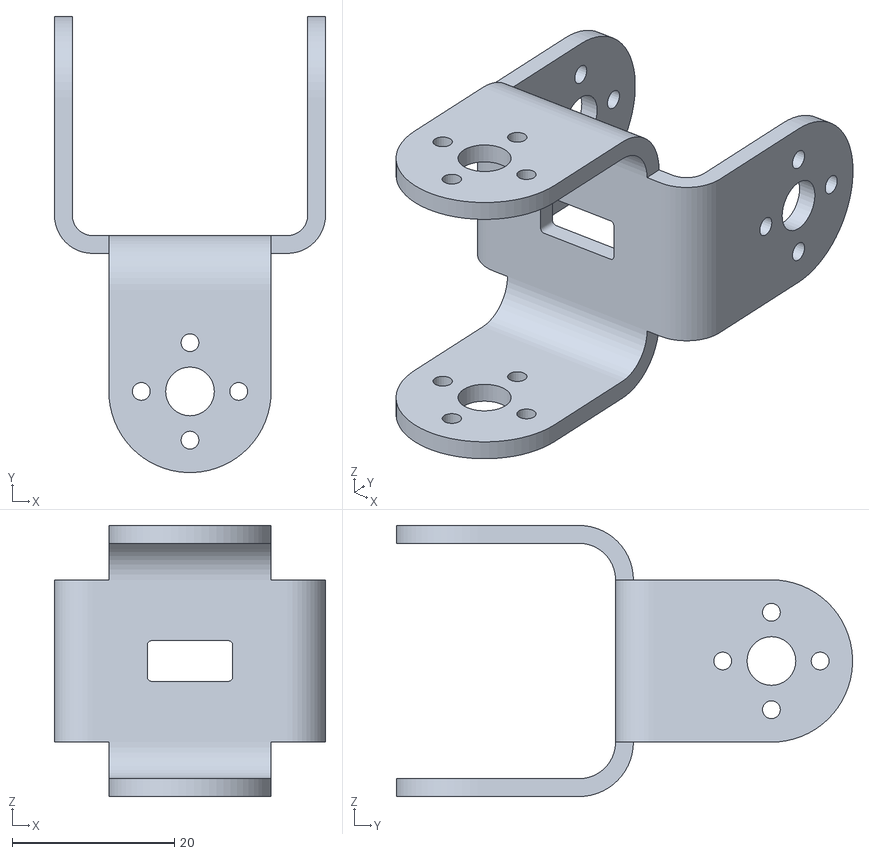
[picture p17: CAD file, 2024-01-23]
hardware/STL/doubleU v9.stl
33.4 x 56.2 x 33.4

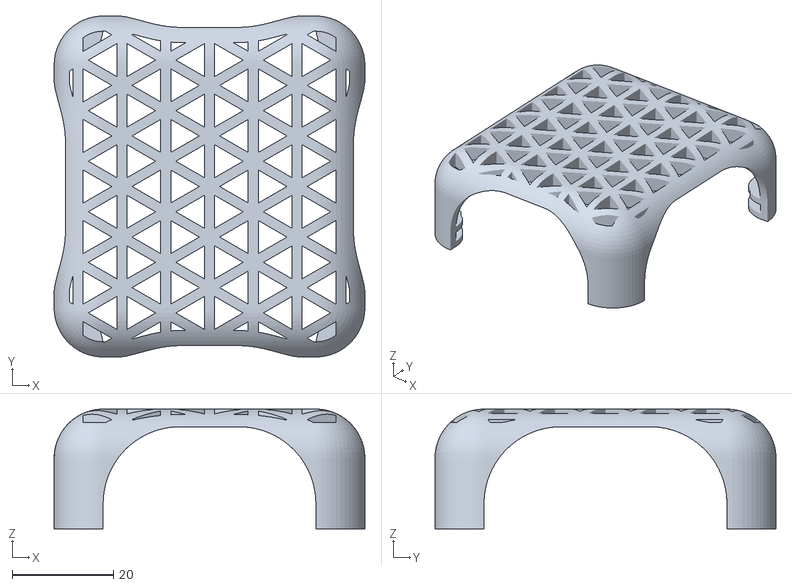
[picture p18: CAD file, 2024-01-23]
hardware/STL/case_bottom v3.stl
61.5 x 67.4 x 23.7

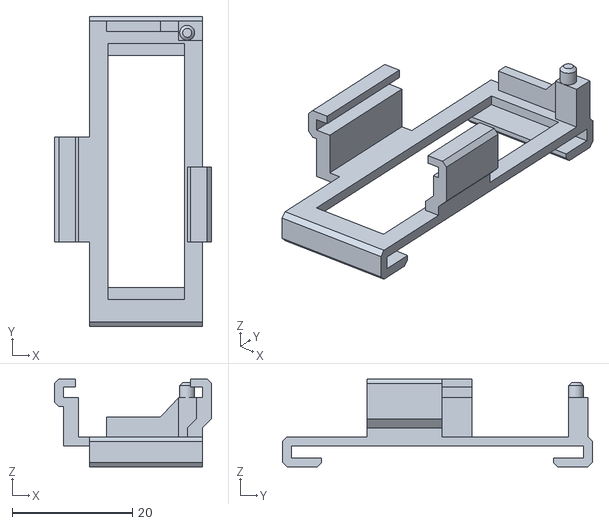
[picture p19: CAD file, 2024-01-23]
hardware/STL/spacer_for_tft v39.stl
26.1 x 51.5 x 14.6

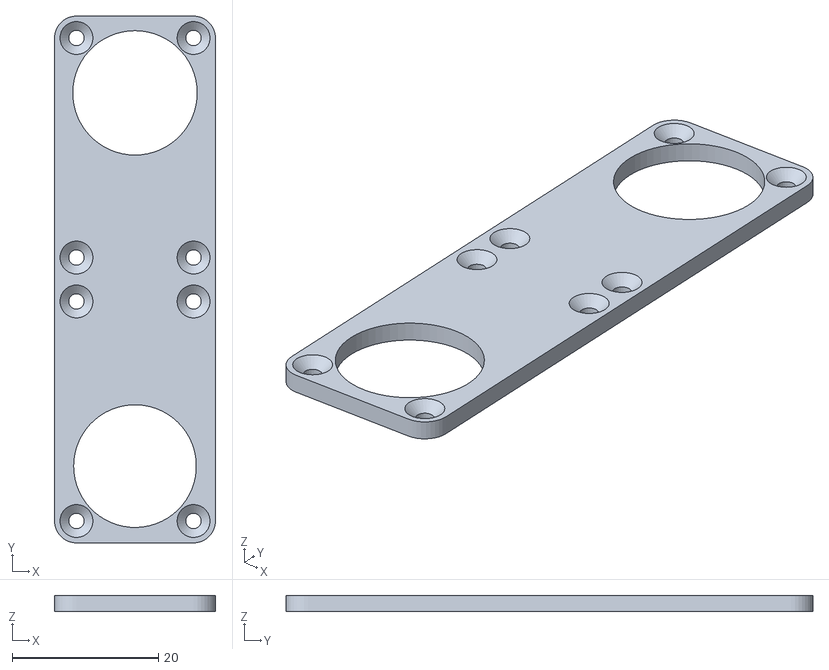
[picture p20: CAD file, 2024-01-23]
hardware/STL/side v8.stl
22.0 x 72.0 x 2.20

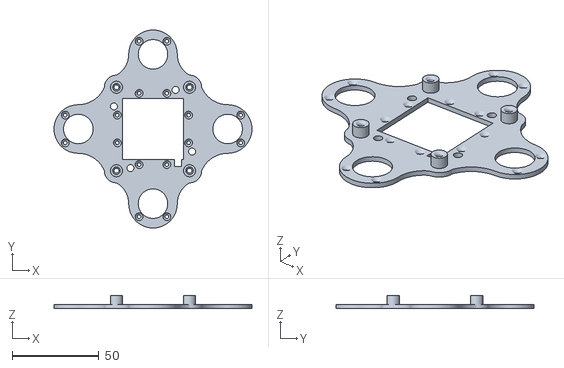
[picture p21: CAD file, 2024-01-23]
hardware/STL/body_base v17.stl
114.0 x 114.0 x 7.20

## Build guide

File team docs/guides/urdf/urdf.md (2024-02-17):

# <center>URDF File Notes</center>

> URDF files ("Unified Robot Description Format") are used as a common language to describe robots based on XML format  
>
> Download URDF extension in VSCode 

---  

### <center>Table of Contents</center>  
|Item|Heading|Sub Contents|
|:---:|:---:|:---:|
| **1.** | [Reference Links](#reference-links) ||
| **2.** | [Overview](#overview) | [Common joint types](#common-joint-types) |
| **3.** | [Template With Description](#template-with-description) | |
| **4.** | [Including Xacro](#including-xacro) | [Main file](#main-file),<br>[Included file](#included-file),<br>[Placeholders](#placeholders),<br>[Xacro notes](#xacro-notes) |
| **5.** | [Creating a URDF File Process and Visualisation](#creating-a-urdf-file-process-and-visualisation) | [Create basic file](#create-basic-file),<br>[Setup environment](#setup-environment),<br>[Visualise urdf](#visualise-urdf),<br>[Further changes and reloading](#further-changes-and-reloading),<br>[Define next link and joint](#define-next-link-and-joint),<br>[Add base_footprint](#add-base_footprint),<br>[Add world_link](#add-world_link),<br>[View TF tree](#view-tf-tree) |

<br>

[⬆ Table of Contents ⬆](#urdf-file-notes)    

---  

### <u>Reference Links</u>  

[ROS-Industrial Website: Intro to URDF](https://industrial-training-master.readthedocs.io/en/melodic/_source/session3/Intro-to-URDF.html)
[Wiki.ros.org/urdf](https://wiki.ros.org/urdf)  
[Links](https://wiki.ros.org/urdf/XML/link)
[Joints](https://wiki.ros.org/urdf/XML/joint)

[⬆ Table of Contents ⬆](#urdf-file-notes)    

---  

### <u>Overview</u>  

* A robot consists of [links](https://wiki.ros.org/urdf/XML/link) and [joints](https://wiki.ros.org/urdf/XML/joint)  
* First break physical robot down into separate `links` (rigid parts of robot)  
* If two separate parts can move independently of each other, then they will need to be separate `links`. They should also be separate, if two parts make sense to be separate (e.g. removable modules or sensors)  
* Choose where origin for `link` should be, doesn't matter too much with exception of rotating links which should be at center of rotation  
* Connections between `links` are `joints` which describe where `links` are in space  
* Each `link` apart from the first one, will have a corresponding `joint` that says what other `link` its connected to (its parent), and how its connected to the parent  
* Each `link` can only have one parent, but can have many child `links`  

<br>  

* Describing joints, we need to specify what **type** of motion it has.  

##### Common joint types:  

|Type|Description|Example|
|:--|:--|:--|
| Revolute | Rotational motion about a point with a fixed start and stop angle (fixed limits) | Robotic arm |
| Continuous | Rotational motion about a point with no fixed limits (can spin freely forever) | A wheel or spinning gripper that can rotate continously |
| Prismatic | Linear translational motion | Linear actuator that moves along a rod |
| Fixed | Child link doesn't move relative to the parent link | Typically used for convenience where it makes more sense to keep things separated |  

[⬆ Table of Contents ⬆](#urdf-file-notes)  

---  

### <u>Template With Description:</u>  

```xml
<?xml version="1.0"?>`  <!-- xml declaration -->
<robot name="my_robots_name"> <!-- root tag, [see including xacro] -->

    <!-- good practice to append suffex '_link' to name -->
    <link name="my_links_name_link"> <!-- represents one link (typically the first link will be empty and to the world) -->

        <visual> <!-- represents what is seen in sim (multiple visual tags can be specified per link tag for different aspects of link) --> 
            <geometry> <!-- represents overall shape (box, cylinder, sphere or path to 3D mesh) -->  
                <!-- dimentions for shapes are in meters -->
            </geometry>
            <origin> <!-- offset for geometry, so it doesn't have to be centred around links origin (xyz is axes, rpy is roll, pitch, yaw) --> 
            </origin>
            <material> <!-- basically the colour --> 
            </material>
        </visual>  

        <collision> <!-- used for physics collision calculations, (multiple collision tags can be specified per link tag for different aspects of link) -->
        <!-- usually same as visual, but may be simpler for computational purposes   -->
            <geometry> <!-- similar to in visual -->
            </geometry>  
            <origin> <!-- similar to in visual --> 
        </collision>  

        <inertial> <!-- used in physics calculations, specifies how link responds to forces -->  
            <mass> 
            <origin> <!-- centre of mass / gravity (balancing point) --> 
            <inertia> <!-- rotational inertia matrix (how distribution of mass affects rotation of the link) --> 
        </inertial> 

    </link>
  
    <!-- good practice to add suffex `_joint` to name   -->
    <!-- helps to have both parent link and child link names in joint name -->
    <joint name="parent_child_joint" type="motion_type"> <!-- represents one joint [see join types]. Joints effectively define the location of the child link with respect to the parent link --> 
        <parent link="parent_link_name" /> <!-- which links this joint defines a relationship between -->
        <child link="child_link_name" />  
        <origin xyz="0.25 0 0.15" rpy="0 0 0" /> <!-- defines relationship between the two links before any motion is applied --> 

        <!-- Following is not required for a fixed joint   -->
        <axis xyz="0 -1 0" /> <!-- which axis the joint moves along or around --> 
        <limit lower="0" upper="${pi/2}" velocity="100" effort="100" /> <!-- determines physical limitations of the joint (upper/lower in radians or meters, velocity in radians/sec or meters/sec, effort limit in newtons or newton meters) -->

    </joint>

    <link name="another_links_name_link">  
    </link>

    <joint name="another_joints_name_joint"> 
    </joint> 

    ...

</robot>
```   

[⬆ Table of Contents ⬆](#urdf-file-notes)  

---  

### <u>Including Xacro</u>  

> ROS provides a tool called Xacro  
> Makes URDF files easier to use and share  
> Allows files to be split up (e.g. core structure / sensors / materials / macros etc.)  
> Allows properties to be defined and then used by name  

<br>  

##### Main file:  
* Filename extension should be `filename.urdf.xacro`  

  ```xml
  <?xml version="1.0"?>  
  <robot xmlns:xacro="http//www.ros.org/wiki/xacro" name="my_robots_name"> <!-- include xacro --> 

      <xacro:include filename="file_to_include_path.xacro" /> <!-- includes another file --> 

      <link> ... </link>  

      <joint> ... </joint> 

      <link> ... </link> 

      <joint> ... </joint>

  </robot>
  ```

<br>  

##### Included file:  
* Filename extension should be `filename.xacro`  

  ```xml
  <?xml version="1.0"?>
  <robot xmlns:xacro="http//www.ros.org/wiki/xacro"> <!-- include xacro (name not required) --> 

      <!-- example defining a material   -->
      <material name="white">  
          <color rgba="1 1 1 1"/> 
      </material> 

  </robot> 
  ``` 

<br>  

##### Placeholders:  

> Placeholders can be used in a variety of ways  

* Properties:  
  ```xml
  <xacro:property name="arm_radius" value="0.5." /> <!-- define a property --> 
  ... 
  <cylinder radius="${arm_radius}" length="7" /> <!-- using a property value by name -->
  ``` 

<br>  

* Mathematical Operations:  
  ```xml
  <cylinder length="${4*arm_radius + pi}"> <!-- Uses the value defined in the property (above) -->
  ``` 

<br>  

* Macros:  
  * Define a template:  
  ```xml
  <xacro:macro name="inertial_box" params="mass x y z *origin">  
      <inertial>  
          <xacro:insert_block name="origin" />  
          <mass value="${mass}" />
          <inertia ixx="${(1/12) * mass * (y*y+z*z)}"  
              *other entries skipped* />  
      </iniertial> 
  </xacro:macro>
  ```  
  * Use the template:  
  ```xml
  <xacro:inertial_box mass="12" x="2" y="3" z="4"> 
      <origin xyz="0 2 4" rpy="0 0 0" />  
  </xacro:inertial_box>
  ``` 
  * Expands to:  
  ```xml
  <inertial> 
      <origin xyz="0 2 4" rpy="0 0 0" />  
      <mass value="12" />
      <inertia ixx="25" />
  </inertial>
  ```

<br>  

##### Xacro notes:

* When files include Xacro and we want to use the URDF file(s), need to first run xacro program  
* The single URDF output file can then be fed directly into the ROS `robot_state_publisher` which then will publish the URDF file on the `/robot_description` topic  
* This can be done with a launch file   

[⬆ Table of Contents ⬆](#urdf-file-notes)  

---  

### <u>Creating a URDF File Process and Visualisation</u>  

##### Create basic file:
* Create file  
  ```shell
  touch filename.urdf
  ```

* Open file in VS code  
  ```shell
  code filename.urdf
  ```

<br>  

* Add xml and robot tags (can be easily done with URDF extension installed)  
  ```xml
  <?xml version="1.0"?>
  <robot name="my_robot">
      <!-- everything else will be written here -->
  </robot>
  ```

<br>  

* Start with base link (chassis), add inside robot tag  
  ```xml
  <!-- first link should be named exactly 'base_link' or can get errors -->
  <link name="base_link"> 
      <visual>
          <geometry>
              <box size="0.6 0.4 0.2" /> <!-- example shape with dimensions in meters -->
          </geometry>
          <origin xyz="0 0 0" rpy="0 0 0" /> <!-- specify origin, start with zeros and adjust after visualising -->
      </visual> 
  </link> 
  ```

<br>  

##### Setup environment:
* Update your apt repository caches  
  ```shell
  sudo apt update
  ```
* Make sure system is up to date
    ```shell
    sudo apt upgrade
    ```
* Ensure ros-humble-desktop is installed
    ```shell
    sudo apt install ros-humble-desktop
    ```  

* Ensure urdf-tutorial (includes rviz) is installed
  ```shell
  sudo apt install ros-humble-urdf-tutorial
  ```

* Source setup bash file
  ```shell
  source /opt/ros/humble/setup.bash
  ```

<br>

##### Visualise urdf:  
* Get path to urdf file
  ```shell
  <!-- navigate to directory containing urdf first -->
  pwd
  ```
* Launch urdf-tuorial and visualise urdf in rviz
  ```shell
  ros2 launch urdf_tutorial display.launch.py model:=/path/to/urdf/file.urdf
  ```

* Under `Displays` > `RobotModel`:
  * `Alpha` can be adjusted to change the transparency of the model  
  * `Links` dropdown allows you to view settings for each link (each with their own Alpha setting)
  * Within each link is a checkbox for `Show Axes`, which will toggle the axes at the origin of each link  

<br>  

##### Further changes and reloading:
* Once you can visualise the file, we can now start working on it and check that changes are reflected when we reload the file
  ```xml
  <!-- change the origin z-axis to half the height of the chassis so it sits on the grid correctly -->
  ...
  <origin xyz="0 0 0.1" rpy="0 0 0" /> <!-- height of box is 0.2 in example above -->
  ...
  ```
* Ensure file has been saved after making changes

* Stop and reload rviz
  ```shell
  CTRL+C <!-- stops rviz -->

  <!-- relaunchs rviz, can also use up key -->
  ros2 launch urdf_tutorial display.launch.py model:=/path/to/urdf/file.urdf
  ```

<br>  

##### Define next link and joint:  
* Next define the next link (rigid part) similar to how the base_link was defined above  
  ```xml
  <!-- define a material colour -->
  <material name="white">
      <color rgba="1 1 1 1" /> <!-- a refers to alpha which is transparency -->
  </material>

  <link name="lidar_link"> 
      <visual>
          <geometry>
              <cylinder radius="0.1" length="0.05" /> <!-- dimensions in meters -->
          </geometry>
          <origin xyz="0 0 0" rpy="0 0 0"/> <!-- specify origin, start with zeros and adjust after visualising -->
          <material name="white" /> <!-- use defined colour -->
      </visual> 
  </link> 
  ```

* Then define the joint to define the relationshipe between the two links we have defined. Joints can all be positioned at the bottom of the file, or between the link definisions by preference    
  ```xml
  <!-- helpful to have parent and child link names in joint name -->
  <joint name="base_lidar_joint" type="fixed">
      <parent="base_link" /> <!-- name must exactly match links name -->
      <child="lidar_link" />
      <origin xyz="0 0 0" rpy="0 0 0" /> <!-- as before, start with 0 and adjust after visualising -->
  </joint>
  ```

* To adjust position, start with **joint origin**, NOT link origin  
  
  > Both joints and links have origins, but they serve different purposes and affect the robot's kinematics differently:  
  > 
  > Link Origin:  
  > * The reference frame of the element ( visual / collision / inertial ) with respect to the reference frame of the link   
  > &nbsp;
  >
  > Joint Origin:  
  > * The transform from the parent link to the child link. The joint is located at the origin of the child link   
  > * Changing the joint origin affects the position and orientation of the joint's axis of rotation or translation  
  > * Modifying the joint origin can alter the joint's behavior and the robot's kinematics  

  ```xml
  <!-- joint origin is offset by height of base_link (0.2) plus half lidar_link (0.05/2) so it sits on top of chassis -->
  <joint name="base_lidar_joint" type="fixed">
      <parent="base_link" />
      <child="lidar_link" />
      <origin xyz="0 0 0.225" rpy="0 0 0" /> 
  </joint>
  ```  
  * **1st** adjust position with joint origin  
  * **2nd** adjust axis of joint if required so any rotational movement is correct. Best way to see this is disable the specific link visual and focus on the TF (transform frame). Use the joint state publisher to move the joint  
  * **3rd** adjust the link origin as required for the visual component  

* Repeat process for each link and joint  

<br>  

##### Add base_footprint:  
* The base_footprint represents a local reference frame for the robot parts, and establishes the robot's internal coordinate system  
* This should be towards the top of the file  
  ```xml
  <!-- add a link and joint to the base_link and offset by the distance to the ground from the base_link origin -->
  <link name="base_footprint_link" /> <!-- link is empty -->

  <joint name="base_joint" type="fixed"> <!-- exception for following convention of parent_child_joint name -->
      <parent link="base_footprint_link" />
      <child link="base_link" />
      <origin xyz="0 0 0.1" rpy="0 0 0" />
  </joint>
  ```
* Now the robot can be visualised using this link in rviz under `Global Options` > `Fixed Frame` and selecting `base_footprint_link`  

<br>  

##### Add world_link:  
* The world_link represents a global reference frame, it defines the absolute coordinate system of the robot's environment  
* This should be towards the top of the file above base_footprint  
  ```xml
  <!-- add a link and joint to base_footprint_link -->
  <link name="world_link" /> <!-- link is empty -->

  <joint name="world_base_footprint_joint" type="fixed">
      <parent link="world_link" />
      <child link="base_footprint_link" />
      <origin xyz="0 0 0" rpy="0 0 0" />
  </joint>
  ```  

<br>  

##### View TF tree:  
* This command will create a pdf and a graphviz file of the TF tree showing all of the links so the relationships can be easily viewed  
  ```shell
  <!-- this needs to be run in another terminal whilst rviz is running -->
  ros2 run tf2_tools view_frames
  ```
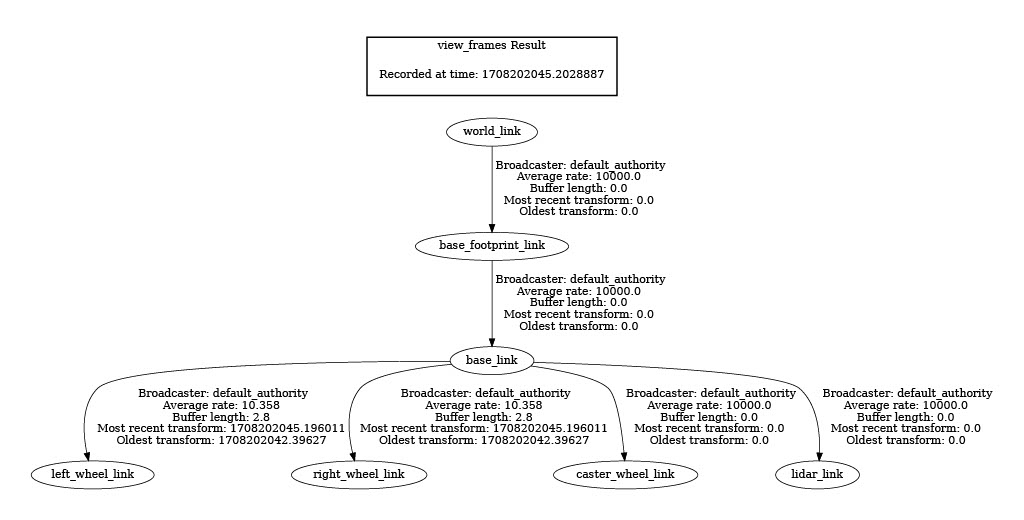
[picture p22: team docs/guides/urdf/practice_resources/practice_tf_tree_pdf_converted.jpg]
TF Tree pdf
  

[⬆ Table of Contents ⬆](#urdf-file-notes)  

---

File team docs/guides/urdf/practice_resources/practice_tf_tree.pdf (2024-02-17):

view_frames Result

Recorded at time: 1708202045.2028887

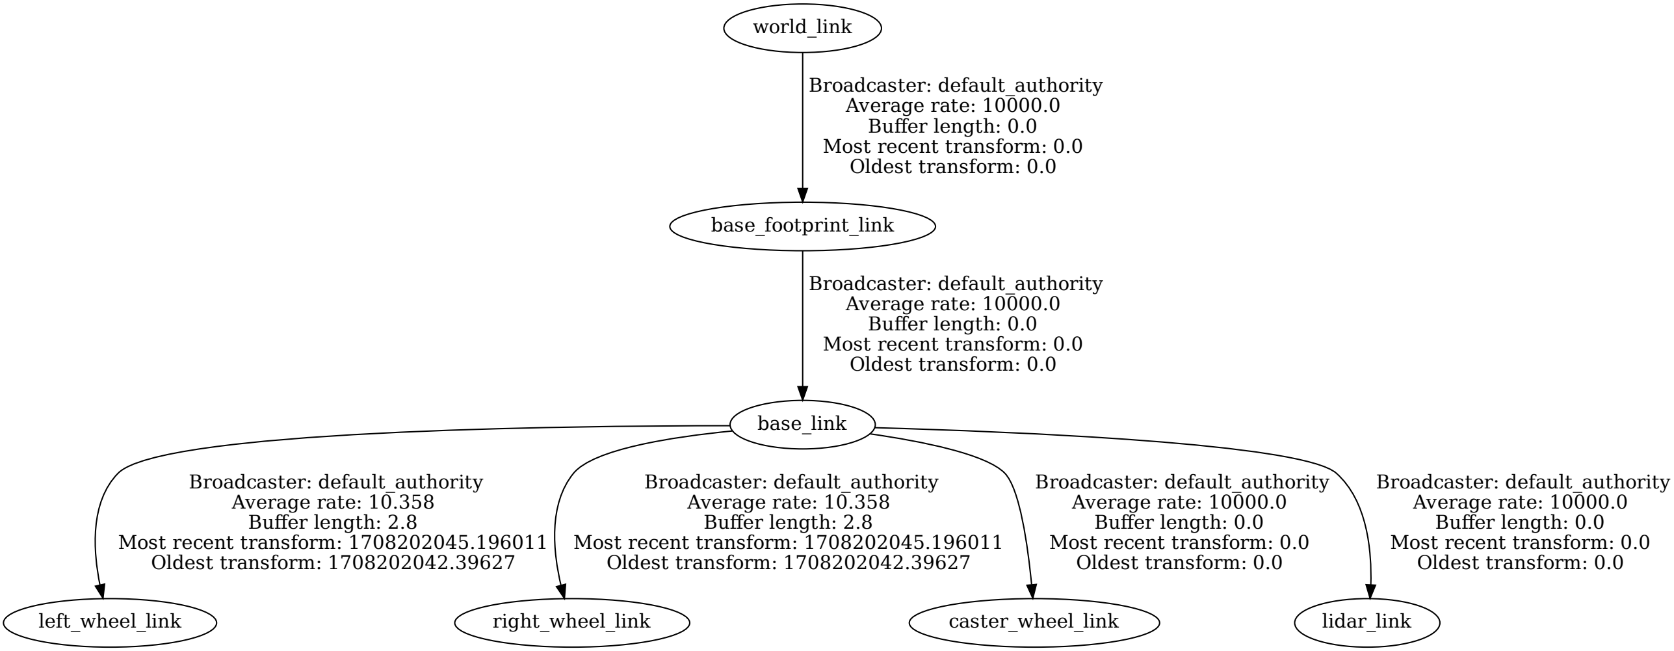
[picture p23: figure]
base_link; left_wheel_link; Broadcaster: default_authority Average rate: 10.358 Buffer length: 2.8 Most recent transform: 1708202045.196011 Oldest transform: 1708202042.39627; right_wheel_link; caster_wheel_link; Broadcaster: default_authority Average rate: 10000.0 Buffer length: 0.0 Most recent transform: 0.0 Oldest transform: 0.0; lidar_link; base_footprint_link; world_link

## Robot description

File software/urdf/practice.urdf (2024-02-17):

<?xml version="1.0"?>
<robot name="practice">

    <material name="grey">
        <color rgba="0.7 0.7 0.7 1"/>
    </material>

    <material name="green">
        <color rgba="0 0.6 0 1"/>
    </material>

    <material name="white">
        <color rgba="1 1 1 1"/>
    </material>

    <link name="world_link" />
    
    <joint name="world_base_footprint_joint" type="fixed">
        <parent link="world_link"/>
        <child link="base_footprint_link"/>
        <origin xyz="0 0 0" rpy="0 0 0"/>
    </joint>

    <link name="base_footprint_link" />
        
    <joint name="base_joint" type="fixed">
        <parent link="base_footprint_link"/>
        <child link="base_link"/>
        <origin xyz="0 0 0.1" rpy="0 0 0"/>
    </joint>

    <link name="base_link">
        <visual>
            <geometry>
                <box size="0.6 0.4 0.2"/>
            </geometry>
            <origin xyz="0 0 0.1" rpy="0 0 0"/>
            <material name="green"/>
        </visual>
    </link>

    <joint name="base_lidar_joint" type="fixed">
        <parent link="base_link"/>
        <child link="lidar_link"/>
        <origin xyz="0 0 0.225" rpy="0 0 0"/>
    </joint>

    <link name="lidar_link">
        <visual name="">
            <geometry>
                <cylinder radius="0.1" length="0.05"/>
            </geometry>
            <origin xyz="0 0 0" rpy="0 0 0"/>
            <material name="white" />
        </visual>
    </link>

    <joint name="base_left_wheel_joint" type="continuous">
        <parent link="base_link"/>
        <child link="left_wheel_link"/>
        <origin xyz="-0.15 0.225 0" rpy="0 0 0"/>
        <axis xyz="0 1 0"/>
    </joint>

    <link name="left_wheel_link">
        <visual>
            <geometry>
                <cylinder radius="0.1" length="0.05"/>
            </geometry>
            <origin xyz="0 0 0" rpy="1.57 0 0"/> <!-- 1.57 radians is 90 degrees-->
            <material name="grey"/>
        </visual>
    </link>

    <joint name="base_right_wheel_joint" type="continuous">
        <parent link="base_link"/>
        <child link="right_wheel_link"/>
        <origin xyz="-0.15 -0.225 0" rpy="0 0 0"/>
        <axis xyz="0 1 0"/>
    </joint>

    <link name="right_wheel_link">
        <visual>
            <geometry>
                <cylinder radius="0.1" length="0.05"/>
            </geometry>
            <origin xyz="0 0 0" rpy="1.57 0 0"/> 
            <material name="grey"/>
        </visual>
    </link>

    <joint name="base_caster_wheel_joint" type="fixed">
        <parent link="base_link"/>
        <child link="caster_wheel_link"/>
        <origin xyz="0.2 0 -0.05" rpy="0 0 0"/>
    </joint>

    <link name="caster_wheel_link">
        <visual>
            <geometry>
                <sphere radius="0.05"/>
            </geometry>
            <origin xyz="0 0 0" rpy="0 0 0"/>
            <material name="grey"/>
        </visual>
    </link>

</robot>

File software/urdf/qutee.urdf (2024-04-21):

<?xml version="1.0"?>
<robot name="qutee_robot">

    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

    <link name="world_link" />
    
    <joint name="world_base_footprint_joint" type="fixed">
        <parent link="world_link"/>
        <child link="base_footprint_link"/>
        <origin xyz="0 0 0" rpy="0 0 0"/>
    </joint>

    <link name="base_footprint_link" />
        
    <joint name="base_joint" type="fixed">
        <parent link="base_footprint_link"/>
        <child link="base_link"/>
        <origin xyz="0 0 0" rpy="0 0 0"/>
    </joint>


    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
    <link name="base_link">
        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

        <inertial>
            <mass value="0.28667"/>
            <origin xyz="0 0 0" rpy="0 0 0"/>
            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
        </inertial>
    </link>


    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
    <joint name="body_bt_sq_joint" type="fixed">
        <parent link="base_link"/>
        <child link="body_bottom_sq_link"/>
        <origin xyz="0 0 -0.0145" rpy="0 0 0"/>
    </joint>

    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
    <link name="body_bottom_sq_link">

        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

        <inertial>
            <mass value="0.09567"/>
            <origin xyz="0 0 0" rpy="0 0 0.7854"/>
            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
        </inertial>
    </link>


    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
    <joint name="body_base_sq_joint" type="fixed">
        <parent link="base_link"/>
        <child link="body_base_sq_link"/>
        <origin xyz="0 0 0.0115" rpy="0 0 0"/>
    </joint>

    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
    <link name="body_base_sq_link">

        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

        <inertial>
            <mass value="0.09567"/>
            <origin xyz="0 0 0" rpy="0 0 0.7854"/>
            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
        </inertial>
    </link>


    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
    <joint name="body_base_sq_top_case_joint" type="fixed">
        <parent link="body_base_sq_link"/>
        <child link="top_case_link"/>
        <origin xyz="0 0 0.01055" rpy="0 0 0"/>
    </joint>

    <link name="top_case_link">
        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

        <inertial>
            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
            <mass value="0.17261"/>
            <origin xyz="0 0 0" rpy="0 0 0"/>
            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
        </inertial>
    </link>


    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
    <joint name="body_bottom_sq_bottom_case_joint" type="fixed">
        <parent link="body_bottom_sq_link"/>
        <child link="bottom_case_link"/>
        <origin xyz="0 0 -0.0089" rpy="0 0 0"/>
    </joint>

    <link name="bottom_case_link">
        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

        <inertial>
            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
            <mass value="0.08877"/>
            <origin xyz="0 0 0" rpy="0 0 0"/>
            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
        </inertial>
    </link>


    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
    <joint name="body_base_sq_front_body_motor_joint" type="fixed">
        <parent link="body_base_sq_link"/>
        <child link="front_body_motor_link"/>
        <origin xyz="0.0355 0 -0.013" rpy="0 0 0"/>
    </joint>

    <link name="front_body_motor_link">
        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

        <inertial>
            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
            <mass value="0.12454"/>
            <origin xyz="0 0 0" rpy="0 0 0"/>
            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
        </inertial>
    </link>

    <joint name="body_base_sq_rear_body_motor_joint" type="fixed">
        <parent link="body_base_sq_link"/>
        <child link="rear_body_motor_link"/>
        <origin xyz="-0.0355 0 -0.013" rpy="0 0 0"/>
    </joint>

    <link name="rear_body_motor_link">
        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

        <inertial>
            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
            <mass value="0.12454"/>
            <origin xyz="0 0 0" rpy="0 0 0"/>
            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
        </inertial>
    </link>

    <joint name="body_base_sq_left_body_motor_joint" type="fixed">
        <parent link="body_base_sq_link"/>
        <child link="left_body_motor_link"/>
        <origin xyz="0 0.0355 -0.013" rpy="0 0 0"/>
    </joint>

    <link name="left_body_motor_link">
        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

        <inertial>
            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
            <mass value="0.12454"/>
            <origin xyz="0 0 0" rpy="0 0 0"/>
            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
        </inertial>
    </link>

    <joint name="body_base_sq_right_body_motor_joint" type="fixed">
        <parent link="body_base_sq_link"/>
        <child link="right_body_motor_link"/>
        <origin xyz="0 -0.0355 -0.013" rpy="0 0 0"/>
    </joint>

    <link name="right_body_motor_link">
        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

        <inertial>
            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
            <mass value="0.12454"/>
            <origin xyz="0 0 0" rpy="0 0 0"/>
            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
        </inertial>
    </link>


    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
    <joint name="front_body_motor_front_doubleu_joint" type="revolute">
        <parent link="front_body_motor_link"/>
        <child link="front_doubleu_link"/>
        <origin xyz="0.0075 0 0.013" rpy="0 0 0"/>
        <axis xyz="0 0 -1"/>
        <limit lower="-1.5708" upper="1.5708" velocity="10.0" effort="10.0"/> 
    </joint>
    

    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
    <link name="front_doubleu_link">
        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

        <inertial>
            <mass value="0.0439"/>
            <origin xyz="0.0181 0 -0.013" rpy="0 0 0"/>
            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
        </inertial>
    </link>

    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
    <joint name="rear_body_motor_rear_doubleu_joint" type="revolute">
        <parent link="rear_body_motor_link"/>
        <child link="rear_doubleu_link"/>
        <origin xyz="-0.0075 0 0.013" rpy="0 0 0"/>
        <axis xyz="0 0 -1"/>
        <limit lower="-1.5708" upper="1.5708" velocity="10.0" effort="10.0"/> 
    </joint>

    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
    <link name="rear_doubleu_link">
        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

        <inertial>
            <mass value="0.0439"/>
            <origin xyz="-0.0181 0 -0.013" rpy="0 0 0"/>
            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
        </inertial>
    </link>

    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
    <joint name="left_body_motor_left_doubleu_joint" type="revolute">
        <parent link="left_body_motor_link"/>
        <child link="left_doubleu_link"/>
        <origin xyz="0 0.0075 0.013" rpy="0 0 0"/>
        <axis xyz="0 0 -1"/>
        <limit lower="-1.5708" upper="1.5708" velocity="10.0" effort="10.0"/> 
    </joint>

    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
    <link name="left_doubleu_link">
        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

        <inertial>
            <mass value="0.0439"/>
            <origin xyz="0 0.0181 -0.013" rpy="0 0 0"/>
            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
        </inertial>
    </link>

    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
    <joint name="right_body_motor_right_doubleu_joint" type="revolute">
        <parent link="right_body_motor_link"/>
        <child link="right_doubleu_link"/>
        <origin xyz="0 -0.0075 0.013" rpy="0 0 0"/>
        <axis xyz="0 0 -1"/>
        <limit lower="-1.5708" upper="1.5708" velocity="10.0" effort="10.0"/> 
    </joint>

    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
    <link name="right_doubleu_link">
        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

        <inertial>
            <mass value="0.0439"/>
            <origin xyz="0 -0.0181 -0.013" rpy="0 0 0"/>
            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
        </inertial>
    </link>


    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
    <joint name="front_doubleu_front_thigh_motor_joint" type="revolute">
        <parent link="front_doubleu_link"/>
        <child link="front_thigh_motor_link"/>
        <origin xyz="0.0362 -0.0156 -0.013" rpy="0 0 0"/>
        <axis xyz="0 1 0"/>
        <limit lower="-1.9199" upper="1.9199" velocity="10.0" effort="10.0"/> 
    </joint>

    <link name="front_thigh_motor_link">
        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

        <inertial>
            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
            <mass value="0.12454"/>
            <origin xyz="0.0075 0.0156 0" rpy="0 0 0"/>
            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
        </inertial>
    </link>

    <joint name="rear_doubleu_rear_thigh_motor_joint" type="revolute">
        <parent link="rear_doubleu_link"/>
        <child link="rear_thigh_motor_link"/>
        <origin xyz="-0.0362 -0.0156 -0.013" rpy="0 0 0"/>
        <axis xyz="0 -1 0"/>
        <limit lower="-1.9199" upper="1.9199" velocity="10.0" effort="10.0"/> 
    </joint>

    <link name="rear_thigh_motor_link">
        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

        <inertial>
            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
            <mass value="0.12454"/>
            <origin xyz="-0.0075 0.0156 0" rpy="0 0 0"/>
            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
        </inertial>
    </link>

    <joint name="left_doubleu_left_thigh_motor_joint" type="revolute">
        <parent link="left_doubleu_link"/>
        <child link="left_thigh_motor_link"/>
        <origin xyz="-0.0156 0.0362 -0.013" rpy="0 0 0"/>
        <axis xyz="-1 0 0"/>
        <limit lower="-1.9199" upper="1.9199" velocity="10.0" effort="10.0"/> 
    </joint>

    <link name="left_thigh_motor_link">
        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

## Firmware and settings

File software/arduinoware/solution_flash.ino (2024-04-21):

// author: Zin Lin Htun
// reviewed by: Team 88 members
// Walk Simple code Arduino
// Using Arduino ARDUINO_AVR_UNO


#include <DynamixelShield.h>
#include <Adafruit_BNO055.h>

// #if defined(ARDUINO_AVR_UNO) || defined(ARDUINO_AVR_MEGA2560)
//   #include <SoftwareSerial.h>
//   SoftwareSerial soft_serial(7, 8); // DYNAMIXELShield UART RX/TX
//   #define DXL soft_serial
// #elif defined(ARDUINO_SAM_DUE) || defined(ARDUINO_SAM_ZERO)
//   #define DEBUG_SERIAL SerialUSB
// #else
//   #define DEBUG_SERIAL Serial
// #endif

#define SERVO_1_ID 1
#define SERVO_2_ID 2

#include <SoftwareSerial.h>
SoftwareSerial soft_serial(7, 8); // DYNAMIXELShield UART RX/TX
#define DXL soft_serial

const uint8_t DXL_ID = 1;
const float DXL_PROTOCOL_VERSION = 2.0;
int x = 1;
DynamixelShield dxl;

//This namespace is required to use Control table item names
using namespace ControlTableItem;
// dynamixel ids
int ids[] = {11, 12, 13, 21, 22, 23, 31, 32, 33, 41, 42, 43};

void neutral_pose(){
  for (uint8_t i = 1; i < 12; i+=3){

    dxl.setGoalPosition(ids[i], 1748);
    //delay(100);
  }

  for (uint8_t i = 0; i < 12; i+=3){

    dxl.setGoalPosition(ids[i], 2048);
    //delay(100);
  }


  for (uint8_t i = 2; i < 12; i+=3){

    dxl.setGoalPosition(ids[i], 1748);
    //delay(100);
  }
}

void setup() {
  // put your setup code here, to run once:

  // Set Port baudrate to 57600bps. This has to match with DYNAMIXEL baudrate.
  dxl.begin(57600);
  // Set Port Protocol Version. This has to match with DYNAMIXEL protocol version.
  dxl.setPortProtocolVersion(DXL_PROTOCOL_VERSION);
  // Get DYNAMIXEL information
  dxl.ping(DXL_ID);

  // Turn off torque when configuring items in EEPROM area
  dxl.torqueOff(DXL_ID);
  dxl.setOperatingMode(DXL_ID, OP_POSITION);
  dxl.torqueOn(DXL_ID);
  for (uint8_t i = 0; i < 12; i++){

    dxl.torqueOff(ids[i]);
    dxl.setOperatingMode(ids[i], OP_POSITION);
    dxl.torqueOn(ids[i]);
    //delay(1000);
  }

  for (uint8_t i = 0; i < 12; i++){

    dxl.setGoalPosition(ids[i], 2048);
    delay(100);
  }

  neutral_pose();

}

// walk functionality
void walk (bool f2e = true){
  // first 2 leggers
  int idsX0 [] = {13, 23};
  for (uint8_t i = 0; i < 2; i++) {

      dxl.setGoalPosition(idsX0[i], 2248);


  }

  delay(200);

  int idsX1 [] = {12, 22};
  for (uint8_t i = 0; i < 2; i++) {

      dxl.setGoalPosition(idsX1[i], 1248);



  }
  delay(200);

  // second 2 leggers
  for (uint8_t i = 6; i < 12; i++) {
    if (i != 6 && i != 9 ){
      dxl.setGoalPosition(ids[i], 1248);
      // delay(100);
    }
  }
  delay(270);

  // for all leggers to return to 0
  neutral_pose();

}

void easy_walk() {
  dxl.setGoalPosition(12, 2048 );
  delay(40);
  dxl.setGoalPosition(13, 2348 );

  delay(400);

  dxl.setGoalPosition(22, 2048 );
  delay(40);
  dxl.setGoalPosition(23, 2348 );

  delay(400);

  dxl.setGoalPosition(33, 2048 );
  delay(40);
  dxl.setGoalPosition(43, 2048 );

  delay(400);

  dxl.setGoalPosition(31, 1748 );
  delay(40);
  dxl.setGoalPosition(41, 2348 );

  delay(400);

  neutral_pose();

}

void loop() {
  // put your main code here, to run repeatedly:
  delay(500);
  // Please refer to e-Manual(http://emanual.robotis.com/docs/en/parts/interface/dynamixel_shield/) for available range of value.
  // DEBUG_SERIAL.println(dxl.ping(1));
  // Set Goal Position in RAW value
  easy_walk();


}

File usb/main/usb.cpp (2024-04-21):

#include "freertos/FreeRTOS.h"
#include "freertos/task.h"
#include "driver/uart.h"
#include "driver/gpio.h"
#include "esp_log.h"
#include "soc/uart_struct.h"
#include "string.h"
#include "driver/spi_master.h"
#include "driver/spi_common.h"
#include <unistd.h>


#define UART_PORT           UART_NUM_1
#define TX_PIN              GPIO_NUM_17   // Replace with your actual GPIO pin number
#define RX_PIN              GPIO_NUM_18  // Replace with your actual GPIO pin number

#define BAUD_RATE           115200
#define TAG "USB"

const int DXL_IDs[] = {1};
void init_uart() {

    uart_config_t uart_config = {
            .baud_rate = BAUD_RATE,
            .data_bits = UART_DATA_8_BITS,
            .parity = UART_PARITY_DISABLE,
            .stop_bits = UART_STOP_BITS_1,
            .flow_ctrl = UART_HW_FLOWCTRL_DISABLE
    };
    ESP_ERROR_CHECK(uart_param_config(UART_PORT, &uart_config));
    ESP_ERROR_CHECK(uart_set_pin(UART_PORT, TX_PIN, RX_PIN, UART_PIN_NO_CHANGE, UART_PIN_NO_CHANGE));
    uart_driver_install(UART_PORT, 1024, 0, 0, NULL, 0);
    uart_set_mode(UART_NUM_1, UART_MODE_RS485_APP_CTRL);
    UART1.rs485_conf.rs485rxby_tx_en = 0;  // don't send while receiving => collision avoidance
    UART1.rs485_conf.rs485tx_rx_en = 1;  // loopback (1), so collision detection works

}



void send_uart_command(uint8_t *command, size_t len) {
    uart_write_bytes(UART_PORT, (const char *)command, len);
}


// calculate crc
uint16_t calculate_crc(const uint8_t *data, size_t length) {
    uint16_t crc = 0xFFFF; // Initialize CRC with 0xFFFF
    for (size_t i = 0; i < length; i++) {
        crc ^= (uint16_t)data[i] << 8; // XOR with next byte
        for (int j = 0; j < 8; j++) {
            if (crc & 0x8000) {
                crc = (crc << 1) ^ 0x1021; // Polynomial division
            } else {
                crc <<= 1; // Shift left
            }
        }
    }
    return crc;
}

void listen_uart_response(uint8_t *buffer, size_t len) {
    uart_read_bytes(UART_PORT, buffer, len, 1000); // Wait indefinitely for response
}

// C for app main because ESP-IDF has a thing for C and not C++, C++: Ouch! Dude Uncool.
extern "C" void app_main() {
    uart_config_t uart_config = {
            .baud_rate = BAUD_RATE,
            .data_bits = UART_DATA_8_BITS,
            .parity = UART_PARITY_DISABLE,
            .stop_bits = UART_STOP_BITS_1,
            .flow_ctrl = UART_HW_FLOWCTRL_DISABLE
    };
    ESP_ERROR_CHECK(uart_param_config(UART_PORT, &uart_config));
    ESP_ERROR_CHECK(uart_set_pin(UART_PORT, TX_PIN, RX_PIN, UART_PIN_NO_CHANGE, UART_PIN_NO_CHANGE));
    uart_driver_install(UART_PORT, 1024, 0, 0, NULL, 0);
    uart_set_mode(UART_NUM_1, UART_MODE_RS485_APP_CTRL);
    UART1.rs485_conf.rs485rxby_tx_en = 0;  // don't send while receiving => collision avoidance
    UART1.rs485_conf.rs485tx_rx_en = 1;  // loopback (1), so collision detection works
    // torque cmd
    uint8_t tor[] = {
            0xFF, 0xFF, 0xFD, 0x00, // Headers and Reserved
            0x01,                    // Packet ID (replace with actual ID)
            0x07, 0x00,              // Length (excluding headers)
            0x03,                    // Instruction (Write)
            0x40, 0x00,         // add: 64 (Little Endian)
            0x01, 0x00,        // value: 1
            0xCA,	0x89        // crc
            // CRC
    };

    // position cmd
    uint8_t cmd[] = {
            0xFF, 0xFF, 0xFD, 0x00, // Headers and Reserved
            0x01,                    // Packet ID (replace with actual motor ID)
            0x09, 0x00,              // Length (excluding headers)
            0x03,                    // Instruction (Write)
            0x74, 0x00,
            0x00, 0x03,              // value: Goal position: 0 (Little Endian)
            0x00, 0x00  , // CRC high
            0xCA,	0x89 // CRC low
            // CRC
    };

    uint8_t ping[] = {
            0xFF, 0xFF, 0xFD, 0x00, // Headers and Reserved
            0x01,                    // Packet ID (replace with actual motor ID)
            0x03, 0x00,              // Length (excluding headers)
            0x01,                    // Instruction (Ping)
            0x19,	0x4E // CRC low
    };

    uint8_t status[] = {
            0x00, 0x00, 0x00, 0x00, // Headers and Reserved,
            0x00,
            0x00,0x00, 0x00,0x00,0x00,
            0x00,0x00,0x00,0x00
    };

    size_t command_len = sizeof(cmd) / sizeof(cmd[0]); // All commands have the same length
    size_t tor_len = sizeof(tor) / sizeof(tor[0]); // All commands have the same length
    size_t pin_len = sizeof(ping) / sizeof(ping[0]); // All commands have the same length

    esp_log_level_set("*", ESP_LOG_INFO); // Set log level to INFO for all components

    // prepare torque
    uint16_t crc = calculate_crc(tor, tor_len - 2);
    uint8_t crc_msb = (crc >> 8) & 0xFF; // Shift right by 8 bits and mask with 0xFF to get the upper byte
    uint8_t crc_lsb = crc & 0xFF;         // Mask with 0xFF to get the lower byte
    tor[tor_len - 2] = crc_lsb;
    tor[tor_len - 1] = crc_msb;

    uint16_t crc_c = calculate_crc(cmd, command_len - 2);
    uint8_t crcc_msb = (crc_c >> 8) & 0xFF; // Shift right by 8 bits and mask with 0xFF to get the upper byte
    uint8_t crcc_lsb = crc_c & 0xFF;         // Mask with 0xFF to get the lower byte
    cmd[command_len - 2] = crcc_lsb;
    cmd[command_len- 1] = crcc_msb;

    vTaskDelay(1000);

    for (int x = 0; x < 10; x++){
        send_uart_command(ping, pin_len); // motor position to 0
        ESP_LOGI(TAG, "Transmitting");

        // Listen for response
        //uint8_t response[14]; // Adjust size according to your expected response
        listen_uart_response(status, sizeof(status));

        // Process response
        // You can add code here to process or log the received response
        ESP_LOG_BUFFER_HEXDUMP(TAG, status, sizeof(status), ESP_LOG_INFO);

        vTaskDelay(200);
    }
}

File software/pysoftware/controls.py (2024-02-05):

# zin
from dynamixel_sdk import *
import dynamixel_sdk as dx1

### PYTHON SECTION FOR CONTROL SET UP

# Set the port and baudrate
DEVICENAME = '/dev/ttyUSB0'  # Modify this according to your setup
BAUDRATE = 57600  # Modify this according to your Dynamixel configuration
# Control table addresses
OG_POS_1 = 228
OG_POS_2 = 1138
ADDR_PRO_MOVING_SPEED = 32
ADDR_START = 116
ADDR_END = 43
ADDR_MAX_POS = 48
TORQUE_ENABLE = 1  # Value for enabling the torque
ADDR_PRO_TORQUE_ENABLE = 1
NEW_POS_1 = 683
NEW_POS_2 = 683
NEW_BACK_POS_1 = 683
NEW_BACK_POS_2 = 1593
# Define protocol version
PROTOCOL_VERSION = 2.0

# Initialize PortHandler instance
portHandler = PortHandler(DEVICENAME)

# Initialize PacketHandler instance
packetHandler = PacketHandler(PROTOCOL_VERSION)
# Open port
if portHandler.openPort():
    print("Succeeded to open the port")
else:
    print("Failed to open the port")
    quit()


# connection control
if portHandler.setBaudRate(BAUDRATE):
    print("Succeeded to change the baudrate")
else:
    print("Failed to change the baudrate")
    exit(1)

d1 = 1
d2 = 2
d3 = 3
d4 = 4
d5 = 5
d6 = 6
d7 = 7
d8 = 8
array_id = [d1, d2, d3, d4, d5, d6, d7, d8]

### END SECTION

##
## Movement will go with 2-2-4

# reset position
def _reset_():
    # For root mortors
    for i in range(4):

        # Set enable torque to move around the servos
        dxl.write1ByteTxRx(portHandler, array_id[i], ADDR_PRO_TORQUE_ENABLE, TORQUE_ENABLE)
        # set max value
        dxl.write2ByteTxRx(portHandler, array_id[i], ADDR_MAX_POS, 1600)

        # Set goal position
        dxl.write4ByteTxRx(portHandler, array_id[i], ADDR_START, OG_POS_1)

    # For adjacent mortors
    for i in range(4,8):
        # Set enable torque to move around the servos
        dxl.write1ByteTxRx(portHandler, array_id[i], ADDR_PRO_TORQUE_ENABLE, TORQUE_ENABLE)
        # set max value
        dxl.write2ByteTxRx(portHandler, array_id[i], ADDR_MAX_POS, 1600)
        # Set goal position
        dxl.write4ByteTxRx(portHandler, array_id[i], ADDR_START, OG_POS_2)

def _reset1_ (id):
    mid = array_id[id-1]
    # Set enable torque to move around the servos
    dxl.write1ByteTxRx(portHandler, mid, ADDR_PRO_TORQUE_ENABLE, TORQUE_ENABLE)

    # Set goal position
    dxl.write4ByteTxRx(portHandler, mid, ADDR_START, OG_POS_1)

    mid = array_id[id - 1] + 4
    dxl.write1ByteTxRx(portHandler,mid, ADDR_PRO_TORQUE_ENABLE, TORQUE_ENABLE)

    # Set goal position
    dxl.write4ByteTxRx(portHandler, mid, ADDR_START, OG_POS_2)


def flash():
    reset()
    print()

# for one leg when pressed w
def _w1_(id):


    mid = array_id[id-1]
    dxl.write1ByteTxRx(portHandler, mid, ADDR_PRO_TORQUE_ENABLE, TORQUE_ENABLE)
    # Set goal position
    dxl.write4ByteTxRx(portHandler, ADDR_START,  NEW_POS_1)

    mid = array_id[id-1] +4
    dxl.write1ByteTxRx(portHandler, mid, ADDR_PRO_TORQUE_ENABLE, TORQUE_ENABLE)
    # Set goal position
    dxl.write4ByteTxRx(portHandler, mid,ADDR_START,  NEW_POS_2)
    print()

# for one leg when pressed s
def _s1_():

    mid = array_id[id-1]
    dxl.write1ByteTxRx(portHandler, mid, ADDR_PRO_TORQUE_ENABLE, TORQUE_ENABLE)
    # Set goal position
    dxl.write4ByteTxRx(portHandler, ADDR_START,  NEW_POS_1)

    mid = array_id[id-1] +4
    dxl.write1ByteTxRx(portHandler, mid, ADDR_PRO_TORQUE_ENABLE, TORQUE_ENABLE)
    # Set goal position
    dxl.write4ByteTxRx(portHandler, mid,ADDR_START,  NEW_POS_2)
    print()


# for one leg when pressed a
def _a1_():
    mid = array_id[id-1]
    dxl.write1ByteTxRx(portHandler, mid, ADDR_PRO_TORQUE_ENABLE, TORQUE_ENABLE)
    # Set goal position
    dxl.write4ByteTxRx(portHandler, ADDR_START,  NEW_POS_1)

    mid = array_id[id-1] +4
    dxl.write1ByteTxRx(portHandler, mid, ADDR_PRO_TORQUE_ENABLE, TORQUE_ENABLE)
    # Set goal position
    dxl.write4ByteTxRx(portHandler, mid,ADDR_START,  NEW_POS_2)
    print()

    print()

# for one leg when pressed d
def _d1_():
    print()

# for one leg when pressed w reposition
def _w2_():

    mid = array_id[id-1]
    dxl.write1ByteTxRx(portHandler, mid, ADDR_PRO_TORQUE_ENABLE, TORQUE_ENABLE)
    # Set goal position
    dxl.write4ByteTxRx(portHandler, ADDR_START,  NEW_BACK_POS_1)

    mid = array_id[id-1]
    dxl.write1ByteTxRx(portHandler, mid, ADDR_PRO_TORQUE_ENABLE, TORQUE_ENABLE)
    # Set goal position
    dxl.write4ByteTxRx(portHandler, mid, ADDR_START,  NEW_BACK_POS_2)
    print()


# for one leg when pressed s reposition
def _s2_():
    print()

# for one leg when pressed a reposition
def _a2_():
    print()

# for one leg when pressed d reposition
def _d2_():
    print()


# for all legs when pressed w
def w ():
    threads = []
    # 2 of 2-2-4
    for i in range (2):
        id = i + 1
        thread = threading.Thread(target=_w1_, args=( id))
        threads.append(thread)
        thread.start()

    # Wait for all threads to complete
    for thread in threads:
        thread.join()

    threads.clear()

    # 2 of 2-2-4
    for i in range (2,4):
        id = i + 1
        thread = threading.Thread(target=_w2_, args=( id ))
        threads.append(thread)
        thread.start()

    # Wait for all threads to complete
    for thread in threads:
        thread.join()

    threads.clear()

    # 4 of 2-2-4
    for i in range (4):
        id = 1+ i
        thread = threading.Thread(target=_reset1_, args=(id))
        threads.append(thread)
        thread.start()

    # Wait for all threads to complete
    for thread in threads:
        thread.join()

    threads.clear()

    print("Moved forward")

# for all legs when pressed s
def s ():
    threads = []


    # 2 of 2-2-4
    for i in range(2, 4):
        id = i + 1
        thread = threading.Thread(target=_w1_, args=(id))
        threads.append(thread)
        thread.start()

        # Wait for all threads to complete
    for thread in threads:
        thread.join()

    # 2 of 2-2-4
    for i in range(2):
        id = i + 1
        thread = threading.Thread(target=_w2_, args=(id))
        threads.append(thread)
        thread.start()


    # Wait for all threads to complete
    for thread in threads:
        thread.join()

    threads.clear()

    # 4 of 2-2-4
    for i in range(4):
        id = 1 + i
        thread = threading.Thread(target=_reset1_, args=(id))
        threads.append(thread)
        thread.start()

    # Wait for all threads to complete
    for thread in threads:
        thread.join()

    threads.clear()

    print("Moved Backward")
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

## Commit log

2024-01-23 regaining Code: credit to OG devs
    [Case_no_tft v2.stl, Case_tft v19.stl, body_base v17.stl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]
2024-01-31 components: credit to OG writers submodules
    [app3M_fat9M_16MB.csv, bare_minimum_2MB.csv, default.csv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]
2024-01-31 removed arduino from busIO
2024-01-31 removed arduino from GFX-LIB
2024-02-01 minutes adjusted for next weeks meeting time, contributions for week 1 added
    [sprint_1.xlsx]
2024-02-05 Walking automatic motor control: OG code only has degree motor control here we walk automatically
2024-02-05 contributions added
    [sprint_2.xlsx]
2024-02-09 initial changes for esp and top casing
    proper measurements need to be carried out
    [Case_tft.stl, esp32-S3-tft-reverse.stl]
2024-02-11 Notes on URDF files and Xacro started
    [template.urdf]
2024-02-14 Changed parts
    Changed due to circuit boards being different sizes
    [Case_tft.stl, body_bottom.stl, esp32-S3-tft-reverse.stl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]
2024-02-14 Deleted body_bottom v24.stl
    [body_bottom v24.stl]
2024-02-14 Deleted foot v20.stl
    [foot v20.stl]
2024-02-14 Deleted tibia v21.stl
    [tibia v21.stl]
2024-02-14 Deleted Case_no_tft v2.stl
    [Case_no_tft v2.stl]
2024-02-17 practice urdf file created and visualised, created tf_tree pdf and graphviz
    [practice.urdf, qutee.urdf]
2024-02-17 guide updated for visualisation and development process, changed directory structure in guides
    [template.urdf]
2024-02-20 Started urdf file
    [qutee.urdf]
2024-02-21 Continued working on urdf, cases and bases complete (visuals)
    [qutee.urdf]
2024-02-22 continuing working on urdf, working on doubleU links
    [qutee.urdf]
2024-02-22 still working on doubleu links
    [qutee.urdf]
2024-02-22 urdf thighs and motors complete (visuals only), still to add legs
    [qutee.urdf]
2024-02-23 urdf visuals finished
    [qutee.urdf]
2024-02-26 updated contribution spreadsheet
    [Contribution.xlsx]
2024-03-09 collision and inertial tags added to urdf
    [qutee.urdf]
2024-03-11 updated contribution spreadsheet for weeks 7 and 8
    [Contribution.xlsx]
2024-03-12 new spacer design
    [new_spacer.stl]
2024-03-18 updated contribution spreadsheet for week 10
    [Contribution.xlsx]
2024-04-03 Joints changed to revolute
    [qutee.urdf]
2024-04-09 updated contributions
    [Contribution.xlsx]
2024-04-21 added arduino software
2024-04-21 Added Documentation
    [app3M_fat9M_16MB.csv, bare_minimum_2MB.csv, default.csv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]
2024-04-21 typo corrected in script comments
    [qutee.urdf]
2024-04-21 Reinstated files which were deleted by mistake
    [practice.urdf]
